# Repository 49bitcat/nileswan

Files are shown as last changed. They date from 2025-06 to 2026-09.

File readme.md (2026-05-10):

# nileswan

Open software, WS/WSC/PCv2 compatible flash cartridge.

## Building instructions

### Requirements

- [OSS CAD Suite](https://github.com/YosysHQ/oss-cad-suite-build) (FPGA core)
  - Requires a modified version of `icepack`, see below for more information
- [Wonderful Toolchain](https://wonderful.asie.pl/wiki/doku.php?id=getting_started)
  - `target-wswan` (IPL1, recovery, updater)
  - `toolchain-gcc-arm-none-eabi` (MCU firmware)
  - `wf-superfamiconv` (IPL1)
  - `wf-zx0-salvador` (IPL1, updater)
- CMake (MCU firmware)
- NASM (IPL0)
- Nim 2.0+ (FPGA core, IPL0)
- Ninja (MCU firmware)
- Python 3.x (SPI images, updater)
  - Including external libraries: `crc`
- dd, dosfstools, mtools (emulator images)

#### icepack

For the FPGA to be ready in time, the bitstream needs to be as small as possible and loaded at the highest speed possible. Thus a [modified branch of icepack](https://github.com/49bitcat/icestorm/tree/nileswan) has to be used.

### Compiling

1. Make sure to fetch the Git submodules: `git submodule update --init --recursive`.
2. Run `make help` to read what build options are possible.
3. Run `make` (or `make ...`) to build the requested components.

## License

- `docs/`: [CC BY-SA 4.0](https://creativecommons.org/licenses/by-sa/4.0/) (user and developer documentation)
- `firmware/`: GNU GPLv3+ (MCU firmware)
- `shell/`: [CC BY-SA 4.0](https://creativecommons.org/licenses/by-sa/4.0/) (cartridge shell STL files)
- `software/`: GNU GPLv3+ (cartridge IPL and on-device tools)
  * `software/libnile/`: zlib AND FatFs license

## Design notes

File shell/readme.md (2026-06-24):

# Shell

**If you previously printed the shell yourself or ordered it somewhere, please note that there was a mistake in the model which sometimes can lead to damage on the PCB. **

This can be easily be fixed by trimming the lid part near the button so that it looks as pictured:

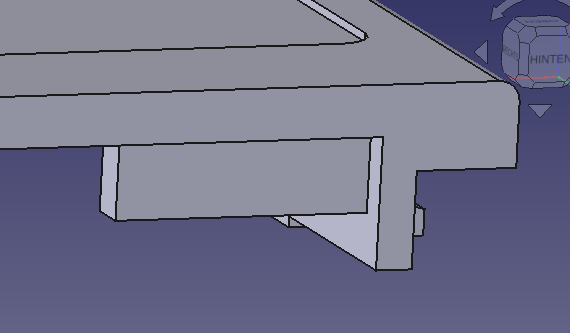
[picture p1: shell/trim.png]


The models have been updated that with the current files the issue does not exist anymore.

The nileswan shell consists of three parts: the bottom part where the PCB is inserted into, the lid which slides on similarly to as is seen on Game Boy cartridges and a cover for the cartridge button. A M2xL2xOD3.2 threaded insert in the lid and an M2x3 flat head screw hold the casing together.

Note that the files here are designed only with FDM printing in mind. They may have bad fitting or may not come out at all with other manufacturing processes.

For FDM printing the lid utilises a custom support piece, which is to be meant to be printed with an incompatible filament so that it can be later be pulled off leaving a clean surface for the label sticker to apply (our shells are printed in PETG with PLA used as support).

The button piece is best printed from PLA, PETG is too "droopy" for the fine details.

The files in this folder are licensed under the terms of [CC BY-SA 4.0](https://creativecommons.org/licenses/by-sa/4.0/).

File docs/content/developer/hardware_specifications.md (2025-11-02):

---
title: 'Hardware overview'
weight: 0
---

nileswan emulates the following hardware:

- Up to 16 MiB of ROM space
- Up to 512 KiB of RAM space, with battery back-up
- 2001 and 2003-compatible I/O ports, including port 0xCE
- Up to 2 KiB of EEPROM space (M93LC46, M93LC76 and M93LC86 compatible), with back-up
- S-3511A compatible real-time clock

In addition, nileswan provides the following native hardware facilities for user homebrew:

- Removable storage card, via SPI interface
- USB port for CDC serial transfers, via MCU and SPI interface
- 512 bytes of inter-process communication memory

## Flowchart

{{< mermaid class="text-center" >}}
flowchart LR
    CB[Cartridge bus]
    BAT[Backup battery]
    FPGA[ICE40HX1K FPGA]
    MCU[STM32U0 MCU]
    PSRAM[16 MiB PSRAM]
    SRAM[512 KiB SRAM]
    FLASH[SPI flash]
    USB[USB port]
    TF[TF card slot]
    ACCEL[Accelerometer]
    BUTTON[External button]

    BAT --> MCU
    BAT --> SRAM
    CB <--> FPGA
    FPGA <-->|SPI| MCU
    FPGA <--> PSRAM
    CB <--> PSRAM
    FPGA <--> SRAM
    CB <--> SRAM
    MCU <--> USB
    FPGA <-->|SPI| TF
    FPGA <-->|SPI| FLASH
    MCU <-->|I²C| ACCEL
    FPGA --- BUTTON
{{< /mermaid >}}

## Board revisions

| External | Internal | BOARD_REVISION |
| --- | --- | --- |
| pre-production | rev. 6 | `0x00` |
| pre-production | rev. 7 | `0x01` |
| pre-production | rev. 8 | `0x02` |
| REV-00 | rev. 9 | `0x02` |

## Limitations

Most of these limitations should not impact end users; however, documenting them may be of use to homebrew developers.

- RTC command timings are slightly slower than on real hardware. This is a compromise between accuracy and power consumption.
- EEPROM write and erase timings are not guaranteed to match real hardware. This may be improved in the future with firmware updates. Note that, in general, EEPROM write and erase timings are not guaranteed to be consistent across cartridges.
- Due to hardware limitations, the emulation of the MBM29DL400TC NOR flash chip used on certain cartridges is very limited. Writes are correctly passed through, but other commands, including erases, may be stubbed or unimplemented.
- The ability to set jumpers using GPIO pins is not yet implemented. This will be resolved in the future with a firmware update.
- No infrared transmitter or transceiver is present on the cartridge board.
- No sonar is connected to the cartridge board.
- If the 8-bit ROM access width is used, the native SPI area is not correctly mapped. This may be resolved in the future with a firmware update.

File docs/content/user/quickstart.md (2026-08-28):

---
title: 'Quick start guide'
weight: 0
---

To set up nileswan, you're going to need a removable storage card, sometimes referred to as a TF card, formatted
using the FAT16 or FAT32 file system.

{{< hint type=note >}}
Cards over 32 gigabytes may be formatted using the exFAT file system by default, which is not supported. In addition, only MBR partition tables are currently supported.

To ensure correct storage card formatting, you may wish to follow [the formatting guide](../troubleshooting/storage-card-formatting).
{{< /hint >}}

You're also going to need a *menu program*. This is the first program launched by nileswan's boot loader, stored in `/NILESWAN/MENU.WS`. The following options are currently available:

* **[swanshell](https://docs.asie.pl/swanshell/user/installation)** - the official main menu program.

{{< hint type=caution >}}
The boot loader doesn't support loading arbitrary programs. Do not use this functionality as an autoboot method; you will be disappointed.
{{< /hint >}}

With a menu program installed, you should be able to turn on your console with the nileswan cartridge inserted. Enjoy!

{{< hint type=note >}}
Unfortunately it is not always possible to ship a nileswan with a battery preinstalled. Please see this [guide](https://www.49bitcat.com/products/nileswan/battery_swap/) on suitable coin cell batteries and how to install them.

There should be a note accompanying your nileswan if the battery could not have been included, though swanshell will also warn you if it does not detect a battery.
{{< /hint >}}

If you run into problems, make sure to check the [Troubleshooting](../troubleshooting) section.

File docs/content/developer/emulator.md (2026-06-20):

---
title: 'Device emulator'
weight: 5
---

In addition to physical hardware, a device emulator can be used for testing nileswan software. There are two options available:

- [nileswan-medem](https://github.com/49bitcat/nileswan-medem/releases), a fork of the [Mednafen](https://mednafen.github.io/) emulator.
- [nileswan-mesem](https://github.com/49bitcat/nileswan-mesem/releases), a fork of the [MesenCE](https://github.com/nesdev-org/MesenCE/) emulator. More capable and accurate, but currently experimental.

These forks are maintained by us, so please do not ask the original/upstream developers questions about it.

The main advantage of the device emulator is that it allows much more rapid test cycles on a development computer. In addition,
stepping and breakpoint functionality is provided for debugging. The main disadvantage is that the emulator only implements
a limited subset of both the console and the cartridge's functionality.

## Installation

1. Download or compile the device emulator.
2. Prepare the emulator files. This can be done by either:
    - [downloading](https://github.com/49bitcat/nileswan/releases) a ready-made build of the package,
    - [compiling](https://github.com/49bitcat/nileswan) the package from source by using the `make dist-emu` command; in this case, the package will be placed in the `out/emulator` directory.
3. Place the emulator files in a directory of your choosing. You should have the following files:
    - `nileswan.ipl0` - a build of the IPL0 (first-stage loader),
    - `nileswan.spi` - a replica of the SPI flash image,
    - `nileswan.img` - a pre-formatted FAT32 image, emulating the removable storage card.
4. Use a tool of choice (for example, `mount -o loop nileswan.img ...` on Linux) to mount the pre-formatted FAT32 image and edit its contents.
5. Run the emulator: `nileswan-... nileswan.ipl0`.

## Supported features

| Feature | nileswan-medem | nileswan-mesem | Notes |
|---|---|---|---|
| SPI interface | Yes | Yes | |
| Power control | Yes | Yes | |
| SPI removable storage | Partial | Partial | Some commands only, <= 2 GiB only |
| SPI flash | Partial | Partial | Some commands only |
| MCU bootloader | Stubbed | Stubbed | MCU flash not stored |
| MCU native | Partial | Partial | Some commands only |
| MCU EEPROM | No | No | |
| MCU RTC | Partial | Partial | |
| MCU CDC transfer | Yes | No | On medem, use `wswan.excomm` config option |
| MCU accelerometer| Stubbed | Stubbed | |
| IPC area | Yes | Yes | |
| Flash FSM | Yes | Yes | |

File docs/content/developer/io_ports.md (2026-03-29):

---
title: 'I/O port map'
weight: 10
---
| Address |Width| Name | Description |
|---|-----|---|---|
| `0xE0` |  2  | SPI_CNT | SPI control register |
| `0xE2` |  1  | POW_CNT | Power control |
| `0xE3` |  1  | EMU_CNT  | Behavior control (EEPROM, flash emulation, ...) |
| `0xE4` |  2  | BANK_MASK  | Mask for bank index |
| `0xE6` (read)  |  1  | BOARD_REVISION | Board revision |
| `0xE6` (write) |  1  | WARMBOOT_CNT | Trigger FPGA warmboot |
| `0xE8` |  1  | IRQ_ENABLE | Cartridge IRQ enable |
| `0xE9` |  1  | IRQ_STATUS | Cartridge IRQ status |

## SPI interface

**`0xE0` - `SPI_CNT` (16-bit, read/write)**
| Bit(s) | Description |
|---|---|
|0-8|SPI transfer length in bytes minus one|
|9-10|Mode (0 = write, 1 = read, 2 = exchange, 3 = wait and read) |
|11|Transfer speed (0 = 24 MHz "high frequency clock", 1 = cartridge bus clock, usually 384 KHz) |
|12-13|Channel select/chip select (0 = no device selected and output to TF channel, 1 = select TF, 2 = select flash, 3 = select μC)|
|14|Memory mapped RX and TX buffer index (0-1)|
|15|Start/busy, when written (0 = abort transfer, 1 = start transfer), when read (0 = idle, 1 = transferring)|

* In read mode all output serial bits are 1. The incoming bits are stored in the RX buffer.
* In write mode bits from the TX buffer are output. The incoming serial bits are discarded.
* In exchange mode the TX buffer is output, while simultaneously the RX buffer is populated with incoming data.
* Wait and read mode behaves like read mode except bytes are only stored with the first byte received which is not 0xFF.

During transfer the data in the TX buffer currently not mapped into the address space is sent out. The received data is stored in the RX buffer currently not memory mapped. The transfer always starts from the beginning of the buffers.

All values besides the transfer abort are read only while a transfer is in progress.

Transfer aborting is not immediate for internal reasons and to allow the transfer to end cleanly on a byte boundary. After an abort is issued the busy bit will continue to be high until the abort is finally completed.

For EEPROM or RTC SPI communication to work, the cartridge serial clock has to be selected.

## Cartridge control

**`0xE2` - `POW_CNT` (8-bit, read/write)**

| Bit(s) | Description |
|---|---|
|0|Enable 24 MHz high frequency clock. (0=off, 1=on (default))|
|1|Enable TF power (0=off (default), 1=on)|
|2|Enable nileswan I/O registers (0=off, 1=on (default))|
|3|Enable 2001 mapper-specific I/O registers (0=off, 1=on (default))|
|4|Enable 2003 mapper-specific I/O registers (0=off, 1=on (default))|
|5|Pull μC BOOT0/μC busy high (0=no/μC may communicate via it, 1=yes)|
|6|Enable SRAM (0=off, 1=on (default))|
|7|μC reset line|

If `0xDD` is written to `POW_CNT` it will reset the entire register even if nileswan registers are disabled. This allows unlocking the nileswan I/O ports after they have been disabled.

Disabling a range of I/O registers only changes their visibility; it does not disable their functiion. E.g. the upper banking bits of the 2003 mapper continue to apply even if the registers used to change them are not accessible anymore.

The μC reset line bit is connected directly to the nRST pin of the microcontroller.

μC BOOT0 controls whether the microcontroller starts from bootloader ROM or programmable flash (see STM32 documentation). The line is shared with busy line for emulated EEPROM operations and is open drain idling at low.

If SRAM is enabled SRAM (banks 0-7) may be selected when accessing the RAM area.

**`0xE3` - `EMU_CNT` (8-bit, read/write)**

| Bit(s) | Description |
|---|---|
|0-1|Emulated EEPROM size (0=128B, 1=1KB, 2=2KB, 3=no EEPROM connected (default))|
|2|Flash emulation enable (0=disabled (default), 1=enabled)|
|3|Emulated ROM bus width (0=16-bit (default), 1=8-bit)|
|4|32 KB SRAM mirroring (0=disabled, 1=enabled)|
|5-7|Unused/0|

See section on EEPROM for details on EEPROM size.

When flash emulation the FPGA will provide minimal emulation of the programming sequences of parallel NOR flash memory for PSRAM accesses.

When 32 KB SRAM mirroring is enabled address line 15 of the SRAM is kept low, hence accesses to the upper 32 KB of each SRAM page are access the first 32 KB. Together with `BANK_MASK` it can be configured as if the cartridge contains a 32 KB SRAM.

**`0xE6` - `BOARD_REVISION` (8-bit, read)**

| Bit(s) | Description |
|---|---|
|0-7|Board revision|

Used for distinguishing boards during firmware updates.

|Value | Description |
|---|---|
| 0x00 | rev. 6 |
| 0x01 | rev. 7 |
| 0x02 | rev. 8 or 9 |
| 0x03 | rev. 9a |

**`0xE6` - `WARMBOOT_CNT` (8-bit, write)**

| Bit(s) | Description |
|---|---|
|0-1|Warmboot image to boot (0-3)|

After writing the FPGA will load one of four FPGA cores from SPI flash depending on the value written. The core image locations are documented in the SPI flash layout.

It may only be written while not running code from the cartridge. After writing, a wait of approximately 20 milliseconds is necessary until the cartridge responds again.

{{< hint type=important >}}
If your FPGA core image does not [enable](https://github.com/YosysHQ/icestorm/pull/332) a faster frequency range,
the wait may need to be as high as 53 milliseconds.
{{< /hint >}}

## Interrupt handling

**`0xE8` - `IRQ_ENABLE` (8-bit, read/write)**

| Bit(s) | Description |
|---|---|
|0|Pass MCU IRQ line|
|1|Pass button held|
|2-7|Unused/0|

**`0xE9` - `IRQ_STATUS` (8-bit, read/write)**

| Bit(s) | Description |
|---|---|
|0|MCU IRQ line|
|1|Button held|
|2-7|Unused/0|

## Banking

**`0xE4` - `BANK_MASK` (16-bit, read/write)**
| Bit(s) | Description |
|---|---|
|0-8|Mask to be applied to ROM bank index|
|9|Use mask for accesses in ROM0 area (0 = no, 1 = yes (default))|
|10|Use mask for accesses in ROM1 area (0 = no, 1 = yes (default))|
|11|Use mask for accesses in RAM area (0 = no, 1 = yes (default))|
|12-15|Mask to be applied to RAM bank index|

To allow booting from bootrom the masks are initialised with all bits set.

Bank mask is always applied to the extended ROM bank (starting from 0x40000).

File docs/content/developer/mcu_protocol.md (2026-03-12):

---
title: 'MCU firmware protocol'
weight: 50
---

This page documents protocols used to communicate with the on-board STM32 MCU via SPI.

## Bootloader protocol

This is the default mode after resetting with BOOT0 pulled high.

For details on this protocol, please refer to the ST Application note AN4286.

## Native mode

This is the default mode after resetting with BOOT0 pulled low.

To initiate a transaction, send a 16-bit little endian value (two bytes) declaring the command ID (in bits 0-6) and parameter (bits 7-15, values 0-511).

Every packet except "Switch to mode" has a response. The response always consists of the response header (two bytes) and the data.

The response header's bits 1-15 are the length of the following data, in bytes; bit 0 is set to 1 if an error has occured (for example, if the command is unknown).

### 0x00 - Echo

Test command. The parameter is the number of bytes to echo, followed by the bytes to echo.

### 0x01 - MCU: Switch to mode

The parameter is the ID of the mode of communication to use going forward:

- `0x00` - command mode
- `0x01` - EEPROM emulation mode
- `0x02` - RTC S-3511A emulation mode
- `0x03` - CDC output mode (transferred SPI bytes are output via USB CDC)
- `0xFF` - standby mode (requires reset to respond to SPI again)

### 0x02 - SPI: Set maximum frequency

The parameter is the maximum SPI transfer frequency that the MCU should be configured for (clock/pin speeds):

- `0x00` - 384 KHz
- `0x01` - 6 MHz
- `0x02` - 24 MHz

The response is 1 on success, 0 on failure.

So far, speeds faster than 384 KHz have been tested with the exception of commands with large (> 2-4 bytes) input parameter buffers.

### 0x03 - MCU: Get unique ID

The response is the unique ID of the chip.

### 0x04 - MCU: Read status information (protocol 1.2+)

The response is the following structure:

- byte 0..1: status
  - bit 0: 0 = RTC using internal clock, 1 = RTC using external clock
  - bit 1: 0 = RTC not active, 1 = RTC active
  - bit 2: 1 = USB plugged in
  - bit 3: 1 = USB connected to host
- byte 2..3: capabilities
  - bit 0: EEPROM
  - bit 1: USB
  - bit 2: accelerometer
  - bit 3: RTC
  - bit 4: battery back up (battery inserted)
- byte 4..5: reserved

This structure may grow in size in the future.

### 0x08 / 0x09 - MCU: Read / Write register (protocol 1.2+)

The parameter is the register address:

- 0x000: IRQ enable
  - bit 0: TF card inserted (edge)
  - bit 1: TF card removed (edge)
  - bit 2: RTC alarm (level)
- 0x001: IRQ status
- 0x002: IRQ status (automatic acknowledgement on read)

Each register is 2 bytes in size, and is passed as the argument or response.

### 0x0F - MCU: Get protocol version

The response is the *major*, followed by the *minor* version of the MCU protocol, as 16-bit little endian unsigned integers each.

| Firmware version | MCU protocol version |
|---|---|
| 1.0.0+ | 1.0 |
| 1.0.1+ | 1.1 |
| 1.1.0+ | 1.2 |

### 0x10 - EEPROM: Set emulation mode

Set the size of the emulated EEPROM:

- `0x00` - no EEPROM
- `0x01` - M93LC06
- `0x02` - M93LC46 compatible
- `0x03` - M93LC56 compatible
- `0x04` - M93LC66 compatible
- `0x05` - M93LC76 compatible
- `0x06` - M93LC86 compatible

The response is 1 on success, 0 on failure.

### 0x11 - EEPROM: Erase all data

The response is empty.

### 0x12 - EEPROM: Read data

The parameter is the number of words to read; the following word is the offset in words.

The response is the bytes read.

### 0x13 - EEPROM: Write data

The parameter is the number of words to write; the following word is the offset in words, then the words to write.

The response is empty.

### 0x14 - RTC: Send command

The parameter is the packet type to send to the emulated S-3511A, followed by the relevant bytes.

The response is the data returned by the emulated S-3511A.

### 0x15 - EEPROM: Get emulation mode

The response is 1 byte - the EEPROM emulation mode.

### 0x16 - MCU: Set save ID

The parameter specifies the save ID location:

- `0x01`: SRAM2 (if the save ID depends on data stored in SRAM2, such as EEPROM),
- `0x02`: RTC backup domain (if it doesn't),
- `0x03`: both.

The command is followed by four bytes of the save ID.

The save ID `0xFFFFFFFF` is reserved and means "no save is stored".

The response is 1 on success, 0 on failure.

### 0x17 - MCU: Get save ID

The parameter specifies the save ID location.

The response is four bytes of the save ID.

### 0x40 - USB: CDC: Read

The parameter is the maximum number of bytes to read. The value 0 is treated as 512 bytes.

The response is the data read from the CDC.

### 0x41 - USB: CDC: Write

The parameter is the number of bytes to write. The value 0 is treated as 512 bytes.

The response is two bytes in size and is the number of bytes successfully written.

### 0x42 - USB: HID: Write

The parameter is the length of the packet.

The data sent is two bytes - the result of a keypad scan.

The response is zero bytes in size.

### 0x43 - USB: CDC: Available

The response is the number of bytes that can be read from the CDC.

### 0x44 - USB: CDC: Clear

Clears the write and read buffers, removing any unread data.

No parameter, no response data.

### 0x50 - Accelerometer polling control

If the parameter is non-zero, the accelerometer is powered up and polled at the frequency equal to the parameter; for example, if the parameter is 100, the accelerometer will be polled at 100 Hz.

The frequency range is 1 .. 510 Hz. The parameter value 511 is reserved. 

If the parameter is zero, accelerometer polling is disabled.

A one byte response is given, 1 if the operation was successful and the accelerometer is present and 0 for the opposite.

### 0x51 - Accelerometer read

Returns three signed 16-bit words representing the measured acceleration on three axis X, Y and Z.

````

Plane representing Swan as held when playing horizontally.

Coordinate system is the local coordinate system of the accelerometer.
-Z is equivalent to the normal of the plane.

               ^ +Y
              /
     ________/________
+X  /       /        /
<----------0        /
  /        |       /
 /_________|______/
           |
           v +Z

````

The accelerometer is configured to work in a range of +/- 2 g with 10 bit fractional precision. This means that when the console is resting, the accelerometer will read a vector of magnitude 1024 the direction opposite to Earth's gravitational pull. E.g. if the console sits on the side with the EXT port a value of approximately (1024, 0, 0) will be read. See also: https://en.wikipedia.org/wiki/Accelerometer#Physical_principles and the datasheet of the used MXC400xXC series accelerometer.

### 0x7F - Reserved

Reserved to distinguish 0xFF bytes from commands.

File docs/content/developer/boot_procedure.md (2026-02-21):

---
title: 'Boot procedure'
weight: 30
---

nileswan uses a two-stage boot loader.

{{< mermaid class="text-center" >}}
flowchart LR
    C[Console IPL] -->|FPGA core 0| A0[IPL0]
    A0 -->|SPI flash| A1[IPL1 /boot/]
    A0 -->|SPI flash - button held| A5[IPL1 /factory/]
    A0 -->|SPI flash - X3 + B held| A3[IPL1 /safe/]
    A3 -->|SPI flash| A4[Recovery]
    A1 -->|FPGA core 1| A2[MENU.WS /on TF card/]
    A5 -->|FPGA core 0| A2[MENU.WS /on TF card/]
{{< /mermaid >}}

## IPL0

The first-stage boot loader is 512 bytes in size. It is stored in the factory FPGA core.

Its goal is to:

- reset the nileswan hardware,
- store the console register and I/O port state in console internal RAM,
- load IPL1 from SPI flash to console internal RAM.

## IPL1

The second-stage boot loader is up to `0x37C0` (14272) bytes in size. It is stored in the SPI flash. It uses a special 16-byte header:

|Offset|Size| Description |
|---|----|---|
| 0x0  | 2  | Load address (typically 0x0040) |
| 0x2  | 2  | Number of 512-byte sectors to load from SPI flash |
| 0x4  | 12 | Reserved |

It has two variants:

### IPL1 (boot)

The "boot" variant is bundled with the storage card driver. Its goal is to:

- validate the IPC memory area and populate it if necessary,
- switch to the update-provided FPGA core (unless the factory version of IPL1 is forced by holding the on-cartridge button),
- load `/NILESWAN/MENU.WS` from the storage card.

The "factory" variant is a version of the "boot" variant which does not load the updated firmware version's FPGA core, allowing
booting the system in the case of a corrupt firmware update.

To distinguish between the two variants, you can check the SPI control port's clock: in the "factory" variant, it is configured
to 384 KHz, while the standard "boot" variant sets it to 24 MHz.

### IPL1 (safe)

The "safe" variant instead reserves space for testing functionality, such as:

- performing a test of onboard PSRAM and SRAM memory,
- allowing to load a dedicated recovery program from SPI flash.

## Recovery

The recovery program is up to 256 KiB in size (or 192 KiB for the factory-provided version). It is formatted like a standard WS cartridge image.

It is better documented as part of the [User Guide](/user/troubleshooting/recovery).

## MENU.WS

The menu program is loaded to the final banks of PSRAM (bank `0xFF` downwards). It is formatted like a standard WS cartridge image.

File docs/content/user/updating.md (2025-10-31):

---
title: 'Updating firmware'
weight: 10
---

It is recommended to use the latest nileswan firmware. To update your firmware, proceed as follows:

1. Ensure your console's battery is fully charged. SPI and MCU flashing operations may cause brief periods of increased power draw.
2. Download the latest firmware update version from [here](https://github.com/49bitcat/nileswan/releases/latest/download/nileswan-fw-update.ws).
3. Launch the `.ws` file.

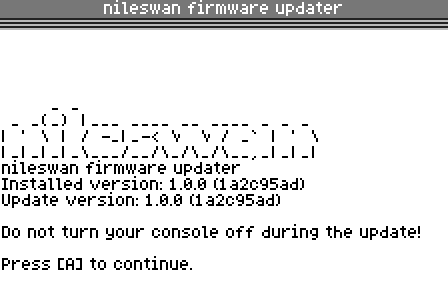
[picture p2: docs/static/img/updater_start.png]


4. After reviewing the messages, press `A` (or `Circle` on PCv2) to install.
5. Wait for the installation to complete. **Do not turn off the console** until the updater tells you it is safe to do so.

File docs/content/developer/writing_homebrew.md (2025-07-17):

---
title: 'Writing homebrew'
weight: 2
---

This article provides a brief overview of the basics of writing homebrew for nileswan. For more detailed information, make sure to study the other articles in the developer guide.

## Libraries

Users of the Wonderful toolchain can use [libnile](https://github.com/49bitcat/libnile), an official C library providing access to most of the cartridge's functionality. Documentation for libnile is available [here](https://49bitcat.com/docs/libnile/).

## Unlocking

After launching a program, nileswan cartridge functionality is locked by default. There are two separate unlocks required to take advantage of all its features, listed below.

### I/O unlock

By default, nileswan I/O ports are locked, that is not writable by software. One can unlock these I/O ports by writing the magic value `0xDD` to port `0xE2` (`POW_CNT`).

{{< hint type=note >}}
One can also write `0x00DD` to disable any cartridge behavior emulation features enabled by the menu program by default.
{{< /hint >}}

Note that this also performs all the operations of this value: disables TF card power, enables 24 MHz clock power, enables SRAM access, disables EEPROM emulation, flash emulation, et cetera. If you're using some of these features differently (such as not making use of the 24 MHz clock), it is recommended to follow this with a write that disables unused functionality.

In libnile, this corresponds to the `nile_io_unlock();` function.

### Bank unlock

However, this doesn't take care of banking.
By default, a mask is applied which prohibits accessing banks outside of the cartridge image's ROM and RAM space by mirroring that space.

In order to allow conveniently accessing nileswan-exclusive banks, functionality is provided to ignore this mask on a per-area basis (SRAM, ROM0, ROM1) via the `BANK_MASK` I/O port. In addition, for ROM banks, one has to use the extended 2003 banking ports (`0xD0`-`0xD5`), as their range on nileswan extends past 8 bits.

{{< hint type=caution >}}
ROM0 and ROM1 are typically allocated from bank `0xFF` down; however, cartridge images are loaded from `0x00` up. Disabling the bank mask on these areas can cause invalid data to be read unless the bank registers are adjusted to match.
{{< /hint >}}

In libnile, the `nile_bank_unlock();` function is provided, which automatically adjusts and unlocks SRAM, ROM0 and ROM1.

## MCU communication

### Initialization

If your homebrew requires nileswan-specific MCU functionality (such as USB access), remember that by default the MCU's native protocol will *not* be available. If the homebrew program requested EEPROM or RTC access, the MCU will be running in an emulation mode for the respective peripheral; otherwise, it would have been shut down to conserve power. As such, accessing the native MCU protocol requires an MCU reset; such a reset will also break non-nileswan-specific EEPROM/RTC communication code from working correctly.

In libnile, the `nile_mcu_reset(false);` function can be used to reset the MCU back to native mode.

### Faster transfer speeds

By default, the MCU is configured to communicate at a frequency of `384 KHz`. In some circumstances, faster communication speeds may be possible. This requires two distinct steps:

- configuring the MCU to accept faster SPI transfers (libnile: `nile_mcu_native_mcu_spi_set_speed_sync(...);`),
- configuring the FPGA and console to emit faster SPI clocks (libnile: `nile_spi_set_speed(...);`).

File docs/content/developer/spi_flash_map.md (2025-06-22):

---
title: 'SPI flash layout'
weight: 40
---

## Write-protected area

This area should be typically write-protected when running software.

|  Start | End | Description  |
|---|---|---|
| 0x000000 | 0x007FFF | FPGA bringup/factory core + header |
| 0x008000 | 0x00BFFF | IPL1 (factory) |
| 0x00C000 | 0x00EFFF | IPL1 (recovery) |
| 0x00F000 | 0x00FFFF | Firmware version (factory) |
| 0x010000 | 0x03FFFF | Recovery software (factory) |

## Non-write-protected area

|  Start | End | Description  |
|---|---|---|
| 0x040000 | 0x043FFF | IPL1 (updated) |
| 0x044000 | 0x04EFFF | Reserved |
| 0x04F000 | 0x04FFFF | Firmware version (updated) |
| 0x050000 | 0x07FFFF | Recovery software (updated) |
| 0x080000 | 0x087FFF | FPGA core 0 |
| 0x088000 | 0x08FFFF | FPGA core 1 |
| 0x090000 | 0x097FFF | FPGA core 2 |
| 0x098000 | 0x09FFFF | FPGA core 3 |
| 0x0A0000 | 0x1FFFFF | Unused (future expansion) |

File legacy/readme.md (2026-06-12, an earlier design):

These are legacy PCB/shell files from an old version of the cartridge's design.

They are kept for historical purposes only and not compatible with the current version of the software.

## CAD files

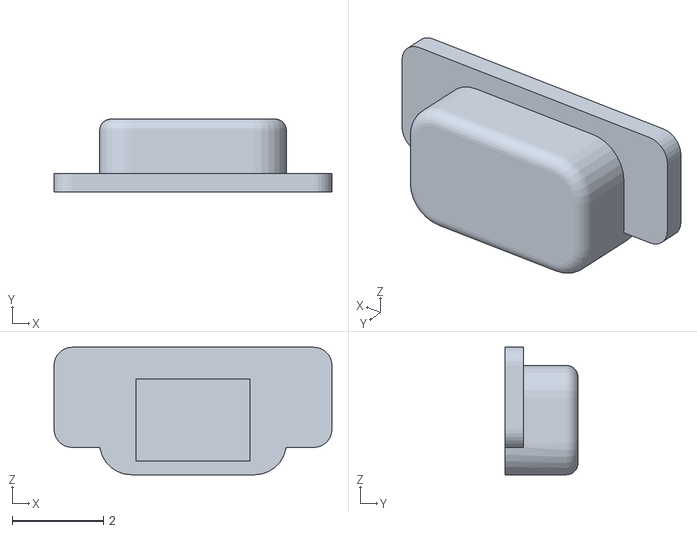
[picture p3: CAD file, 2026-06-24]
shell/nileswanButton.stl
6.10 x 1.60 x 2.80

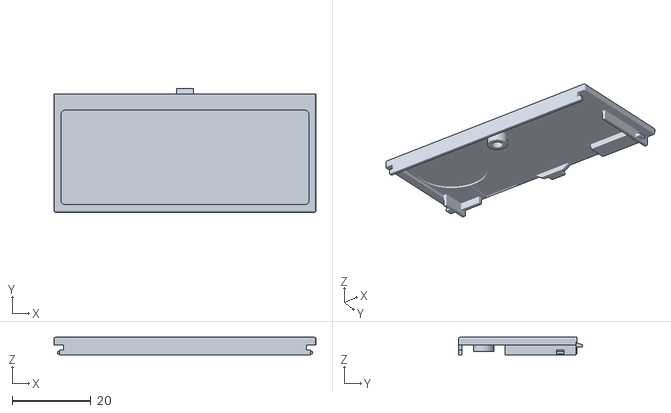
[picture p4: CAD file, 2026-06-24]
shell/nileswanLid.stl
66.6 x 31.5 x 4.50

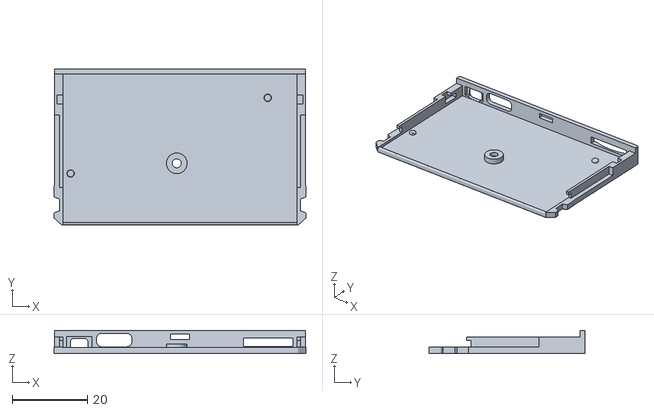
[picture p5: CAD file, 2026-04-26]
shell/nileswanBottomPart.stl
66.8 x 41.5 x 6.20

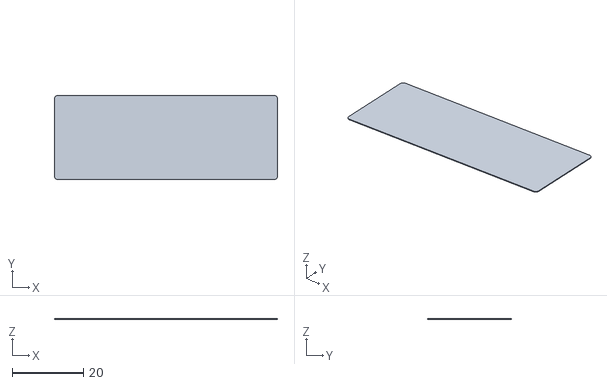
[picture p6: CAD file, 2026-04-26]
shell/nileswanLidPLASupport.stl
62.7 x 23.7 x 0.2

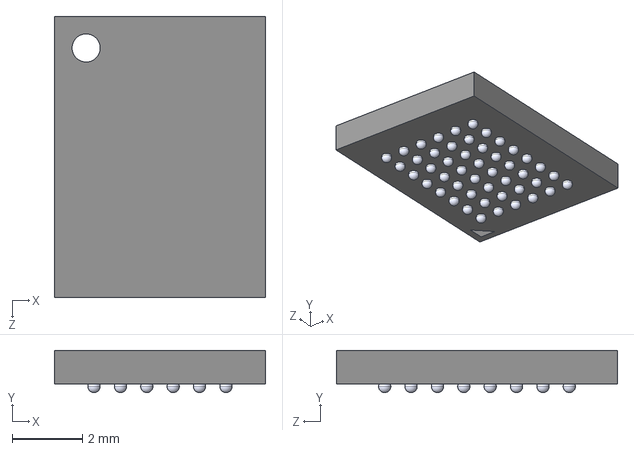
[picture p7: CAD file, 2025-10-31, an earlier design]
legacy/pcb/snapeda/models/IS66WVE4M16EBLL-70BLI.STEP
6.00 x 1.20 x 8.00 mm

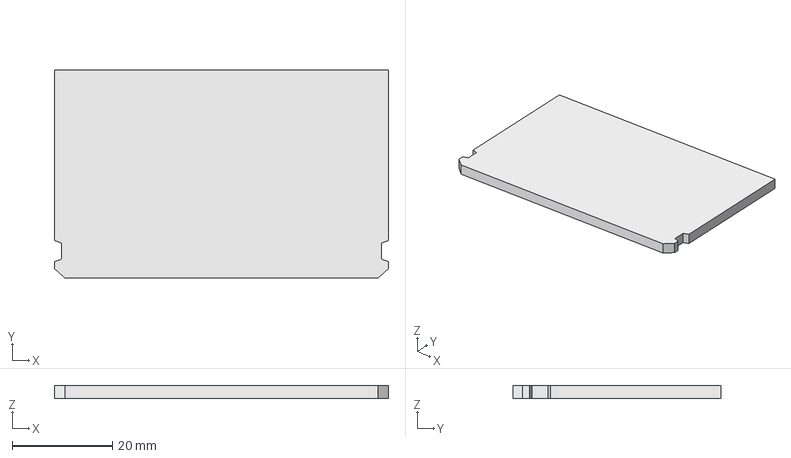
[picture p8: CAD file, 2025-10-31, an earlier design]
legacy/shell/shell.FCStd
66.5 x 41.5 x 2.60 mm

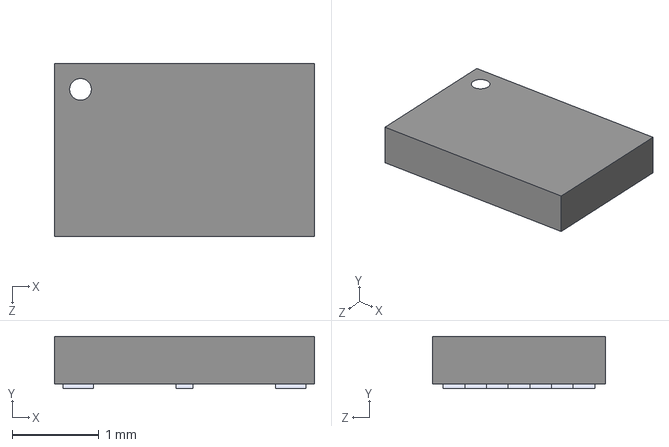
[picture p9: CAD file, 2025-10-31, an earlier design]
legacy/pcb/snapeda/models/W25Q16JVUXIQ.step
3.00 x 0.6 x 2.00 mm

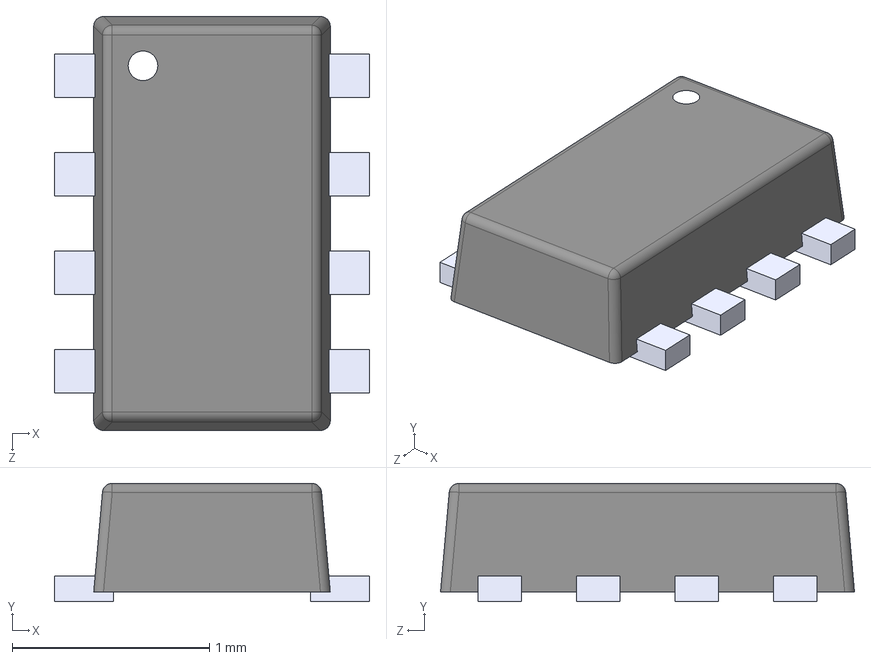
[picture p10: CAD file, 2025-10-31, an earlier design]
legacy/pcb/snapeda/models/TPS2117DRLR.step
1.60 x 0.6 x 2.10 mm

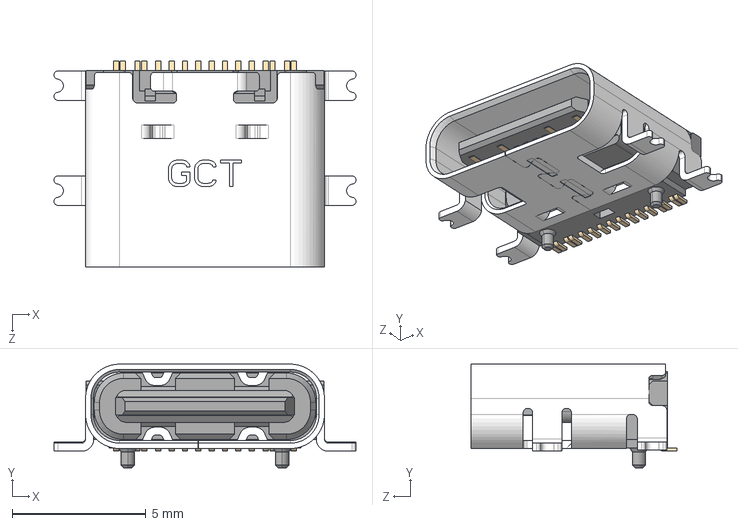
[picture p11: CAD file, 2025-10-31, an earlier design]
legacy/pcb/snapeda/models/USB4110GFA.step
11.3 x 3.89 x 7.70 mm

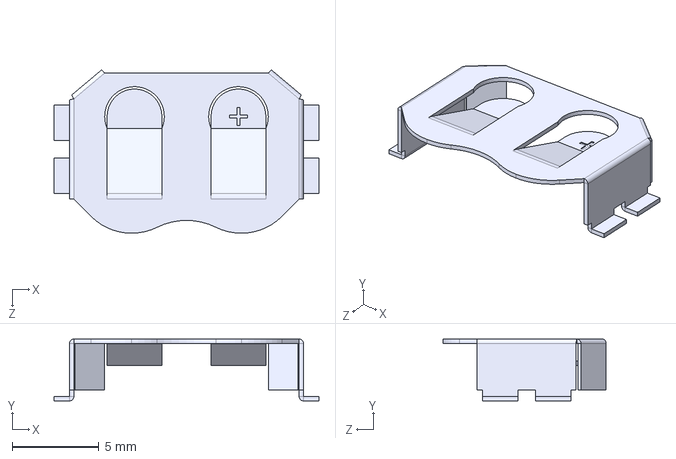
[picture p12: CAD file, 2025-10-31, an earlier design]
legacy/pcb/snapeda/models/BAT-HLD-012-SMT.step
15.2 x 3.56 x 9.40 mm

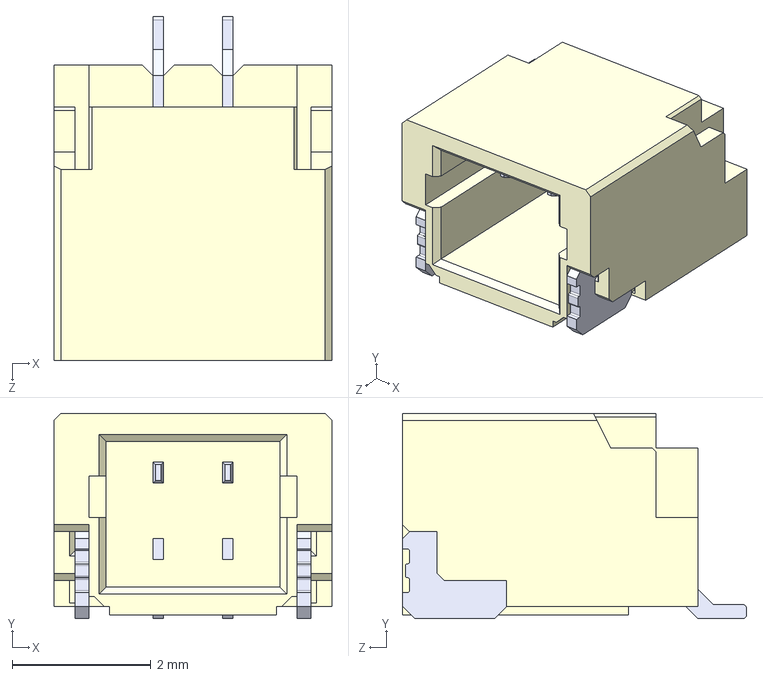
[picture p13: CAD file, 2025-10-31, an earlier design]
legacy/pcb/snapeda/models/SM02B-SRSS-TB_LF__SN_.step
4.00 x 2.95 x 4.95 mm

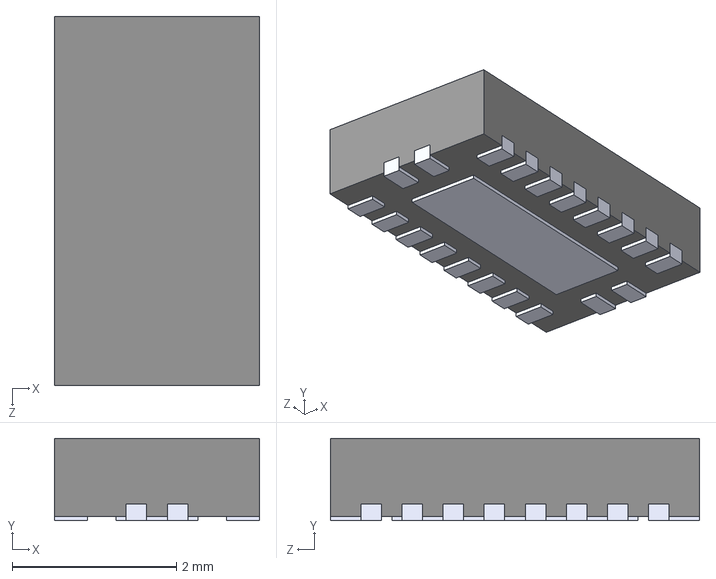
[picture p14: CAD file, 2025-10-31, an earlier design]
legacy/pcb/snapeda/models/74LVC245ABQ.step
2.50 x 1.00 x 4.50 mm

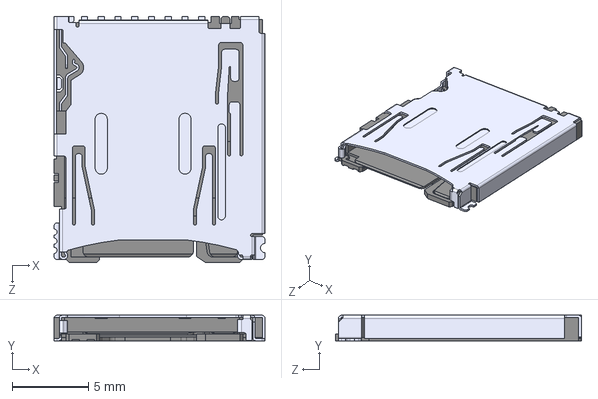
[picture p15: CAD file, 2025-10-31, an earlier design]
legacy/pcb/snapeda/models/DM3AT-SF-PEJM5--3DModel-STEP-418109.STEP
13.8 x 1.68 x 16.2 mm

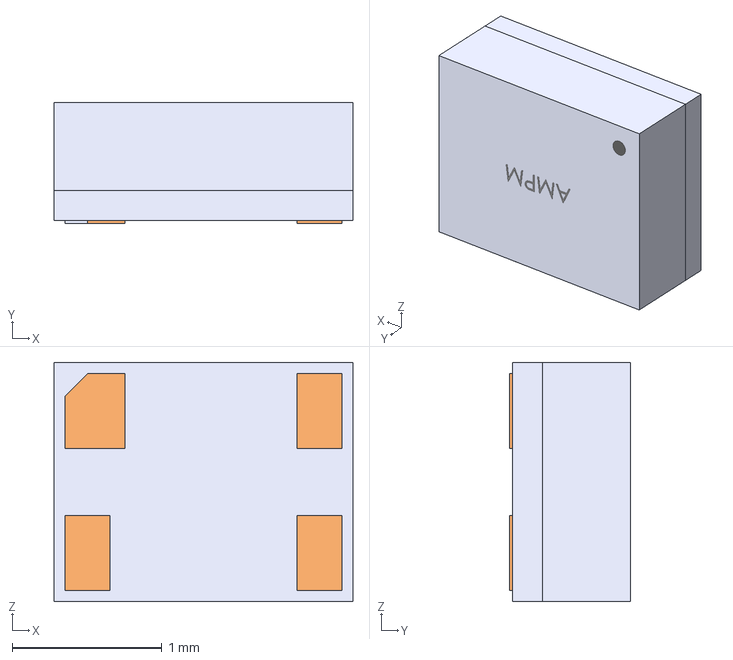
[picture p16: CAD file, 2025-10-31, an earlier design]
legacy/pcb/snapeda/models/AMPMAMPM_2.0 x 1.6 mm.step
2.00 x 0.811 x 1.60 mm

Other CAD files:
legacy/pcb/snapeda/models/SIT8021AI-J4-XXS-24.000000E.step
legacy/pcb/snapeda/models/W25Q16JVZPIQ.STEP
legacy/pcb/snapeda/models/TPS3619-50DGK.step

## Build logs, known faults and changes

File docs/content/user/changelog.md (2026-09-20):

---
title: 'Changelog'
weight: 100
---

## nileswan firmware DEV

- Bootloader
  - Added: Self-test routine for detecting some types of pin contact issues.
  - Changed: Improved compatibility with very early prototype consoles.
- Recovery
  - Fixed: The `Flash MCU firmware` option now flashes the correct firmware for the detected board revision.

## nileswan firmware 1.2.6 (26th August 2026)

- MCU firmware
  - Fixed: Improved battery power management.

## nileswan firmware 1.2.5 (21st June 2026)

- MCU firmware
  - Fixed: Issue regarding EEPROM memory management.
- Recovery
  - Added: SRAM/EEPROM data retention tests.
  - Added: Battery-backed MCU information lookup and tests.
  - Changed: Re-arranged menu hierarchy to be more user friendly.

## nileswan firmware 1.2.4 (16th June 2026)

- MCU firmware
  - General reliability improvements.

## nileswan firmware 1.2.3 (15th June 2026)

- FPGA core
  - General reliability improvements.
- MCU firmware
  - General reliability improvements.

## nileswan firmware 1.2.2 (7th June 2026)

- MCU firmware
  - General reliability improvements.
- Recovery IPL
  - Added: New quick memory test, focused on detecting address/data line faults.
  - Added: Visible warning for 24 MHz oscillator faults.
  - Fixed: Extended memory test failing all subsequent banks if one fails.
  - Fixed: ID readout in cases where the 24 MHz oscillator is non-functional.
- Updater
  - Added: Expanded SPI flash chip support.

## nileswan firmware 1.2.1 (13th May 2026*)

- Recovery
  - Changed: Tweaked manufacturing test.
- As this version does not change anything for end users, it will not be
  released as a flashable update.

## nileswan firmware 1.2.0 (10th May 2026)

- Factory FPGA core
  - Fixed: PCv2 consoles always starting in slow SPI mode.
  - Fixed: Improved startup reliability on aging "mono" WS consoles.
  - Note: These fixes requires a full reflash to be performed.
- MCU firmware
  - Fixed: Issues when querying the accelerometer while USB is plugged in.
  - Fixed: Issues when querying the onboard battery status.
- Recovery
  - Fixed: PCv2 input layout mapping.
- Updater
  - Fixed: PCv2 input layout mapping.

## nileswan firmware 1.1.1 (29th March 2026)

- MCU firmware
  - Fixed: Gamepad mode not functioning correctly on Windows machines.
  - Fixed: Issues when using the EEPROM mode while USB is plugged in.
  - Fixed: Worked around certain RTC mode reliability issues.
- Recovery
  - Added: MCU EEPROM test.

## nileswan firmware 1.1.0 (5th March 2026)

- FPGA core
  - Added: Emulation of the 0xCF I/O port mirror.
  - Added: Hardware support for faster SPI buffer access methods.
  - Fixed: Disabled I/O ports remaining readable.
  - Other minor improvements.
- Bootloader
  - Changed: Improved startup time.
- MCU firmware
  - Added: Support for detecting TF card insertion/removal.
  - Added: Support for reporting MCU status information back to console.
  - Fixed: Potential crash after disconnecting USB cable.
  - Fixed: Uncommon glitches during RTC communication.
- Recovery
  - Added: MCU status query tool.
  - Added: TF card insertion/removal test.
  - Fixed: Updated recovery program not using the updated FPGA core.

## nileswan firmware 1.0.3 (14th February 2026)

- MCU firmware
  - Updated: TinyUSB.
- Recovery
  - Added: onboard button test.
  - Added: PSRAM-SRAM stability test.
  - Added: TF card stability test.
  - Changed; Improved TF card benchmarks.
  - Fixed: Issues with TF card formatting.
- Other minor fixes and improvements.

## nileswan firmware 1.0.2 (18th November 2025)

- Bootloader:
  - Minor load time optimizations (~3-5% improvement).
- Recovery:
  - Fixed soft reset functionality.
  - Fixed storage card benchmarks not working without a forced re-initialization in some cases.
  - Fixed storage card formatting not working with some cards.
- Other minor fixes and improvements.

## nileswan firmware 1.0.1 (10th November 2025)

- MCU firmware:
  - Fixed response logic for undefined MCU commands.
  - Minor improvements to RTC and USB power management.
- Recovery:
  - Added support for printing cartridge information via USB.
  - Added support for printing the active MCU firmware's protocol version.
- Other minor fixes and improvements.

## nileswan firmware 1.0.0 (29th October 2025)

- Initial release.

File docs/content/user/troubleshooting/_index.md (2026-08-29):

---
title: 'Troubleshooting'
weight: 40
---

This page lists various nileswan issues that may be encountered, as well as solutions.

## Startup problems

### Console does not turn on with cartridge inserted

If no other cartridges work, this implies a fault with the console; fixing your console is outside the scope of this documentation.

If other cartridges work, the nileswan cartridge's contacts may be dirty. Clean up any dirt or grime on the contacts, then try re-inserting the cartridge.

Another option, particularly for original "mono" WS consoles, is that the capacitors have aged to a point where voltage ramps up too slowly for the nileswan cartridge to initialize.
If the console turns on unreliably, or the cartridge otherwise works fine on "color" units, this may be the reason. In this situation (and in general!), it is recommend to replace the console's capacitors.

{{< hint type=caution >}}
If you own a batch 1 nileswan, making a full *reflash* firmware update to version 1.2.0 or newer should help alleviate the problem.
{{< /hint >}}

Another option is that the factory FPGA core data may be corrupt. This is a brick scenario which cannot be recovered in software; as such, you will need to use an external SPI flashing device to resolve it.

Finally, there may be a hardware fault with the cartridge itself.

### Console displays a blank screen after finishing the splash screen sequence

This issue typically points to SPI flash data corruption.

The factory FPGA and IPL data may be intact. If so, follow the [Recovery -> Fixing corrupt update data](recovery#fixing-corrupt-update-data) guide, then install the latest firmware update.

If this alone does not help, the factory FPGA core data itself may be corrupt. In this case, software recovery cannot be guaranteed; as such, you will need to use an external SPI flashing device to resolve it.

## IPL problems

The initial program loader, or IPL, is responsible for loading an user-provided menu program from the removable storage card. In the case of an error, the screen turns black and an error message is displayed, like so:

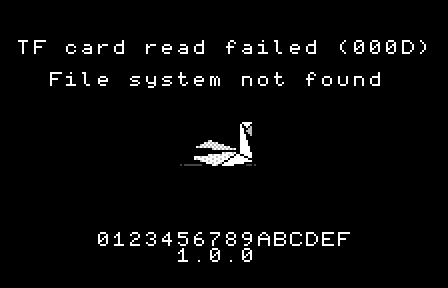
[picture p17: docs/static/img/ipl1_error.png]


Here are some common error messages. Note that an error may also point to a software bug, which may need to be reported to the developers.

**Pin contact error**

This can mean one of two issues:

- More commonly, this means a contact issue has been detected on one or more of the cartridge pins. Clean the cartridge contacts and try again.
- Less commonly, it can point towards a PSRAM chip fault. Launch the safe mode menu and use the *board check* or *memory test* option to diagnose the memory chips.

**Storage not ready**

The removable storage card was not detected. Please try re-inserting it.

**Storage I/O error**

The removable storage card was detected, but an error occured while reading from it. This could point to a hardware fault with the card itself.

**FAT filesystem not found**

The removable storage card was detected, but a FAT16/FAT32 file system was not detected.

nileswan does not currently support exFAT file systems or GPT partition tables. If your card is formatted using exFAT, you will need to manually format it to use FAT32. This is typically a problem for cards larger than 32 GiB.

**File not found**

The menu file (`/NILESWAN/MENU.WS`) was not found on the cartridge.

## Other problems

### Persistent data (save data, date/time, ...) corruption

This issue implies the SRAM and/or MCU are not receiving power.

Make sure a battery is inserted and that the battery holds charge. If that does not resolve the issue, it may point to a software bug or hardware fault.

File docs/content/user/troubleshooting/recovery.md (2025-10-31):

---
title: 'Recovery menu'
weight: 10
---

nileswan features a recovery menu.

1. Start the console while holding the **X3 + B** button combination (or **Esc + Up** on PCv2) to boot into safe mode. 

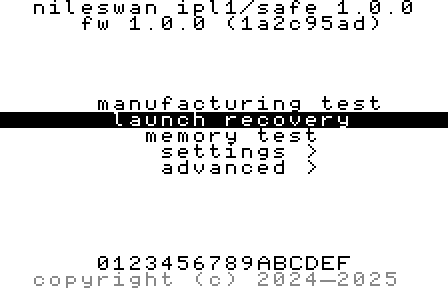
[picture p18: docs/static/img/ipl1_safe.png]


2. Use the up and down buttons to navigate to the **launch recovery** option, then press A (or **Circle** on PCv2).

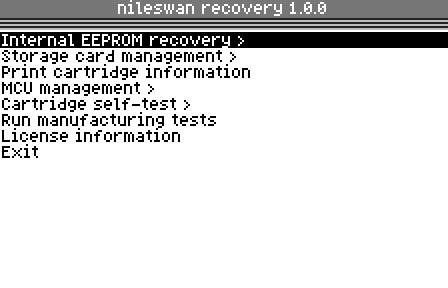
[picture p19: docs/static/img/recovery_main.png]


### Internal EEPROM recovery

Some console issues are caused by internal EEPROM corruption:

- a freeze on start can indicate corrupt splash screen data,
- LCD display issues can indicate corrupt LCD timing data on SC consoles with a TFT panel.

nileswan provides tools which may help in repairing a console with corrupt internal EEPROM data.

#### Disable custom splash

To disable custom splash on boot, one can use the following recovery feature:

1. Hold the button at the top of the cartridge.
2. While holding the button, turn on the console.

This forces the console's IPL to skip any splash screen data in the internal EEPROM.

A permanent solution is offered by the `Internal EEPROM recovery -> Disable custom splash` option in the cartridge recovery program.

#### Restore TFT panel data

To fix TFT panel display issues on SC consoles, one can use the `Internal EEPROM recovery -> Restore TFT panel data` option in the cartridge recovery program.

### Storage card management

This menu provides features related to managing the removable storage card, as well as evaluating its performance.

### Setup MCU boot flags

This is a manufacturing option used to configure the boot sequence of the microcontroller used on nileswan.

### Cartridge self-test

The cartridge comes with a set of self-test features used during manufacturing. These may allow you to diagnose certain hardware and firmware faults yourself. You can also run them in sequence with the `Run manufacturing tests` option.

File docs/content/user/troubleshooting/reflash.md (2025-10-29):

---
title: 'Firmware restore'
weight: 30
---

The IPL1 (second stage bootloader) or FPGA bitstream data may be corrupted as the result of a failed regular update.
This can manifest as a blank screen or as a crash on the initial splash screen (before the menu program is loaded).

nileswan provides a way to boot from the original firmware flashed at manufacturing. One can force the use of the factory IPL1 and FPGA bitstream by proceeding as follows:

1. Hold the physical button at the top of the cartridge.
2. While holding the physical button, turn on the console.
3. Keep holding the physical button until the console's splash screen appears.

From here, you should be able to use the menu software to perform [a standard firmware update](../../updating).

## Factory reflash

Alternatively, if one so chooses, one can also perform a full factory reflash. This updates both the regular and manufacturing copies of the
firmware.

{{< hint type=warning >}}
If the factory reflash fails, the cartridge may be bricked in a way which requires external SPI flashing.

You are performing this procedure at your own risk!
{{< /hint >}}

1. Ensure your console's battery is fully charged.
2. Download the latest firmware reflash image version from [here](https://github.com/49bitcat/nileswan/releases/latest/download/nileswan-fw-reflash.ws).
3. Launch the `.ws` file.
4. After reviewing the messages, press `A` (or `Circle` on PCv2) to install.
5. Wait for the installation to complete. **Do not turn off the console** until the updater tells you it is safe to do so.

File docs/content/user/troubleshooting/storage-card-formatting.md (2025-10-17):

---
title: 'Storage card formatting'
weight: 20
---

nileswan has been tested with external storage cards up to 32 GiB in size. Storage cards formatted with the FAT16 or FAT32 file system up to 2 TiB in size should be supported as well. **exFAT is not currently supported!**

## Via recovery menu

The most reliable way to format the external storage card is using the on-device recovery menu.

1. Start the console while holding the **X3 + B** button combination (or **Esc + Up** on PCv2). You will enter the cartridge's safe mode.
2. Use up/down buttons to navigate to the **launch recovery** option, then press A (or **Circle** on PCv2).
3. Navigate to **Storage card management**, then to **Format storage card**.
4. Follow the on-screen instructions.

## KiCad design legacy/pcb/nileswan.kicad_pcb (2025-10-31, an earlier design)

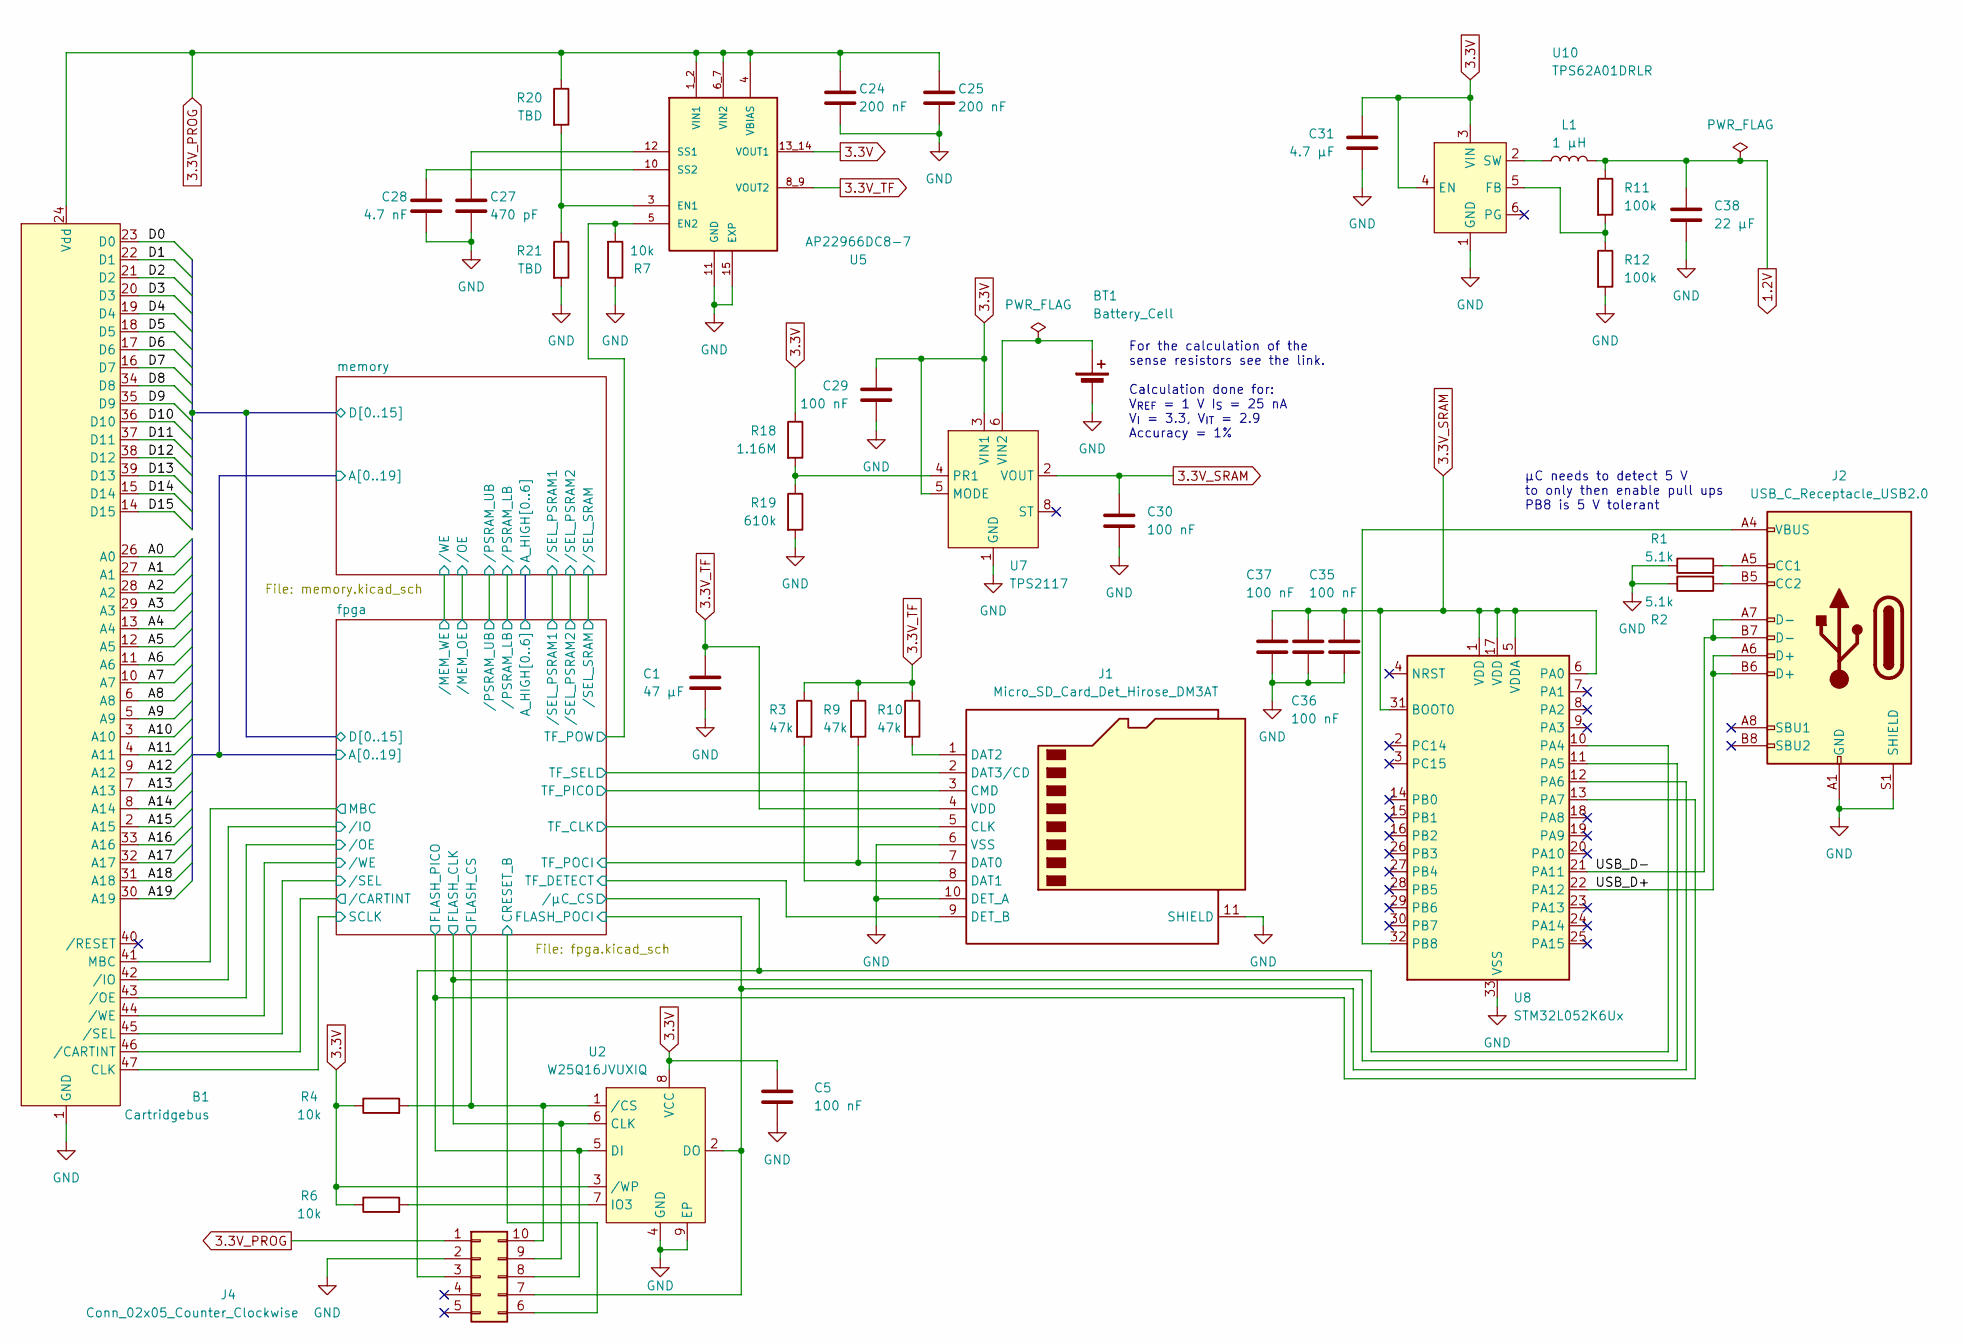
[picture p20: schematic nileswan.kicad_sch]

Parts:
B1: Cartridgebus; WSCartridgeBus
BT1: Battery_Cell; BAT_BAT-HLD-012-SMT
C1: 47 μF; C_0805_2012Metric
C5, C29, C30, C35, C36, C37: 100 nF; C_0402_1005Metric
C24, C25: 200 nF; C_0402_1005Metric
C27: 470 pF; C_0402_1005Metric
C28: 4.7 nF; C_0402_1005Metric
C31: 4.7 μF; C_0603_1608Metric
C38: 22 μF; C_0603_1608Metric
J1: Micro_SD_Card_Det_Hirose_DM3AT; microSD_HC_Hirose_DM3AT-SF-PEJM5
J2: USB_C_Receptacle_USB2.0; USB_C_Receptacle_GCT_USB4110
J4: Conn_02x05_Counter_Clockwise; Tag-Connect_TC2050-IDC-NL_2x05_P1.27mm_Vertical
L1: 1 μH; L_Murata_DFE201610P
R1, R2: 5.1k; R_0402_1005Metric
R3, R9, R10: 47k; R_0402_1005Metric
R4, R6, R7: 10k; R_0402_1005Metric
R11, R12: 100k; R_0402_1005Metric
R18: 1.16M; R_0402_1005Metric
R19: 610k; R_0402_1005Metric
R20, R21: TBD; R_0402_1005Metric
U2: W25Q16JVUXIQ; SON50P300X200X60-9N
U5: AP22966DC8-7; IC_AP22966DC8-7; PARTREV 3-2
U7: TPS2117; SOTFL50P160X60-8N
U8: STM32L052K6Ux; QFN-32-1EP_5x5mm_P0.5mm_EP3.45x3.45mm
U10: TPS62A01DRLR; SOT-563

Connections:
1.2V: C38.1, L1.2, R11.1; also elsewhere on the board
3.3V: C5.1, C29.1, C31.1, R4.1, R6.1, R18.1, U2.3 (/WP), U2.8 (VCC), U5.13_14 (VOUT1), U7.3 (VIN1), U7.5 (MODE), U10.3 (VIN), U10.4 (EN); also elsewhere on the board
3.3V_PROG: B1.24 (Vdd), B1.25 (Vdd), C24.1, C25.1, J4.1, R20.1, U5.1_2 (VIN1), U5.4 (VBIAS), U5.6_7 (VIN2)
3.3V_SRAM: C30.1, C35.1, C36.1, C37.1, U7.2 (VOUT), U7.7 (VOUT), U8.1 (VDD), U8.5 (VDDA), U8.6 (PA0), U8.17 (VDD), U8.31 (BOOT0); also elsewhere on the board
3.3V_TF: C1.1, J1.4 (VDD), R3.1, R9.1, R10.1, U5.8_9 (VOUT2)
/USB_D+: J2.A6 (D+), J2.B6 (D+), U8.22 (PA12)
/USB_D-: J2.A7 (D-), J2.B7 (D-), U8.21 (PA11)
/fpga/A0: B1.26 (A0); also elsewhere on the board
/fpga/A1: B1.27 (A1); also elsewhere on the board
/fpga/A2: B1.28 (A2); also elsewhere on the board
/fpga/A3: B1.29 (A3); also elsewhere on the board
/fpga/A4: B1.13 (A4); also elsewhere on the board
/fpga/A5: B1.12 (A5); also elsewhere on the board
/fpga/A6: B1.11 (A6); also elsewhere on the board
/fpga/A7: B1.10 (A7); also elsewhere on the board
/fpga/A8: B1.6 (A8); also elsewhere on the board
/fpga/A9: B1.5 (A9); also elsewhere on the board
/fpga/A10: B1.3 (A10); also elsewhere on the board
/fpga/A11: B1.4 (A11); also elsewhere on the board
/fpga/A12: B1.9 (A12); also elsewhere on the board
/fpga/A13: B1.7 (A13); also elsewhere on the board
/fpga/A14: B1.8 (A14); also elsewhere on the board
/fpga/A15: B1.2 (A15); also elsewhere on the board
/fpga/A16: B1.33 (A16); also elsewhere on the board
/fpga/A17: B1.32 (A17); also elsewhere on the board
/fpga/A18: B1.31 (A18); also elsewhere on the board
/fpga/A19: B1.30 (A19); also elsewhere on the board
/fpga/CRESET_B: J4.6; also elsewhere on the board
/fpga/D0: B1.23 (D0); also elsewhere on the board
/fpga/D1: B1.22 (D1); also elsewhere on the board
/fpga/D2: B1.21 (D2); also elsewhere on the board
/fpga/D3: B1.20 (D3); also elsewhere on the board
/fpga/D4: B1.19 (D4); also elsewhere on the board
/fpga/D5: B1.18 (D5); also elsewhere on the board
/fpga/D6: B1.17 (D6); also elsewhere on the board
/fpga/D7: B1.16 (D7); also elsewhere on the board
/fpga/D8: B1.34 (D8); also elsewhere on the board
/fpga/D9: B1.35 (D9); also elsewhere on the board
/fpga/D10: B1.36 (D10); also elsewhere on the board
/fpga/D11: B1.37 (D11); also elsewhere on the board
/fpga/D12: B1.38 (D12); also elsewhere on the board
/fpga/D13: B1.39 (D13); also elsewhere on the board
/fpga/D14: B1.15 (D14); also elsewhere on the board
/fpga/D15: B1.14 (D15); also elsewhere on the board
/fpga/FLASH_CLK: J4.9, U2.6 (CLK), U8.11 (PA5); also elsewhere on the board
/fpga/FLASH_CS: J4.10, R4.2, U2.1 (/CS); also elsewhere on the board
/fpga/FLASH_PICO: J4.8, U2.5 (DI), U8.13 (PA7); also elsewhere on the board
/fpga/FLASH_POCI: J4.7, U2.2 (DO), U8.12 (PA6); also elsewhere on the board
/fpga/MBC: B1.41 (MBC); also elsewhere on the board
/fpga/SCLK: B1.47 (CLK); also elsewhere on the board
/fpga/TF_CLK: J1.5 (CLK); also elsewhere on the board
/fpga/TF_DETECT: J1.9 (DET_B); also elsewhere on the board
/fpga/TF_PICO: J1.3 (CMD); also elsewhere on the board
/fpga/TF_POCI: J1.7 (DAT0), R9.2; also elsewhere on the board
/fpga/TF_POW: R7.2, U5.5 (EN2); also elsewhere on the board
/fpga/TF_SEL: J1.2 (DAT3/CD); also elsewhere on the board
/fpga//CARTINT: B1.46 (/CARTINT); also elsewhere on the board
/fpga//IO: B1.42 (/IO); also elsewhere on the board
/fpga//OE: B1.43 (/OE); also elsewhere on the board
/fpga//SEL: B1.45 (/SEL); also elsewhere on the board
/fpga//WE: B1.44 (/WE); also elsewhere on the board
/fpga//μC_CS: J4.3, U8.10 (PA4); also elsewhere on the board
GND: B1.1 (GND), B1.48 (GND), BT1.2 (-), C1.2, C5.2, C24.2, C25.2, C27.2, C28.2, C29.2, C30.2, C31.2, C35.2, C36.2, C37.2, C38.2, J1.6 (VSS), J1.10 (DET_A), J1.11 (SHIELD), J2.A1 (GND), J2.A12 (GND), J2.B1 (GND), J2.B12 (GND), J2.S1 (SHIELD), J4.2, R1.1, R2.1, R7.1, R12.2, R19.2, R21.2, U2.4 (GND), U2.9 (EP), U5.11 (GND), U5.15 (EXP), U7.1 (GND), U8.33 (VSS), U10.1 (GND); also elsewhere on the board
unnamed: BT1.1 (+), U7.6 (VIN2)
unnamed: J1.8 (DAT1), R3.2
unnamed: J1.1 (DAT2), R10.2
unnamed: J2.A5 (CC1), R1.2
unnamed: J2.B5 (CC2), R2.2
unnamed: R6.2, U2.7 (IO3)
unnamed: R20.2, R21.1, U5.3 (EN1)
unnamed: C27.1, U5.12 (SS1)
unnamed: C28.1, U5.10 (SS2)
unnamed: R18.2, R19.1, U7.4 (PR1)
unnamed: J2.A4 (VBUS), J2.A9 (VBUS), J2.B4 (VBUS), J2.B9 (VBUS), U8.32 (PB8)
unnamed: R11.2, R12.1, U10.5 (FB)
unnamed: L1.1, U10.2 (SW)

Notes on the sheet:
μC needs to detect 5 V to only then enable pull ups PB8 is 5 V tolerant
For the calculation of the sense resistors see the link. Calculation done for: V_{REF} = 1 V I_{S} = 25 nA V_{I} = 3.3, V_{IT} = 2.9 Accuracy = 1%

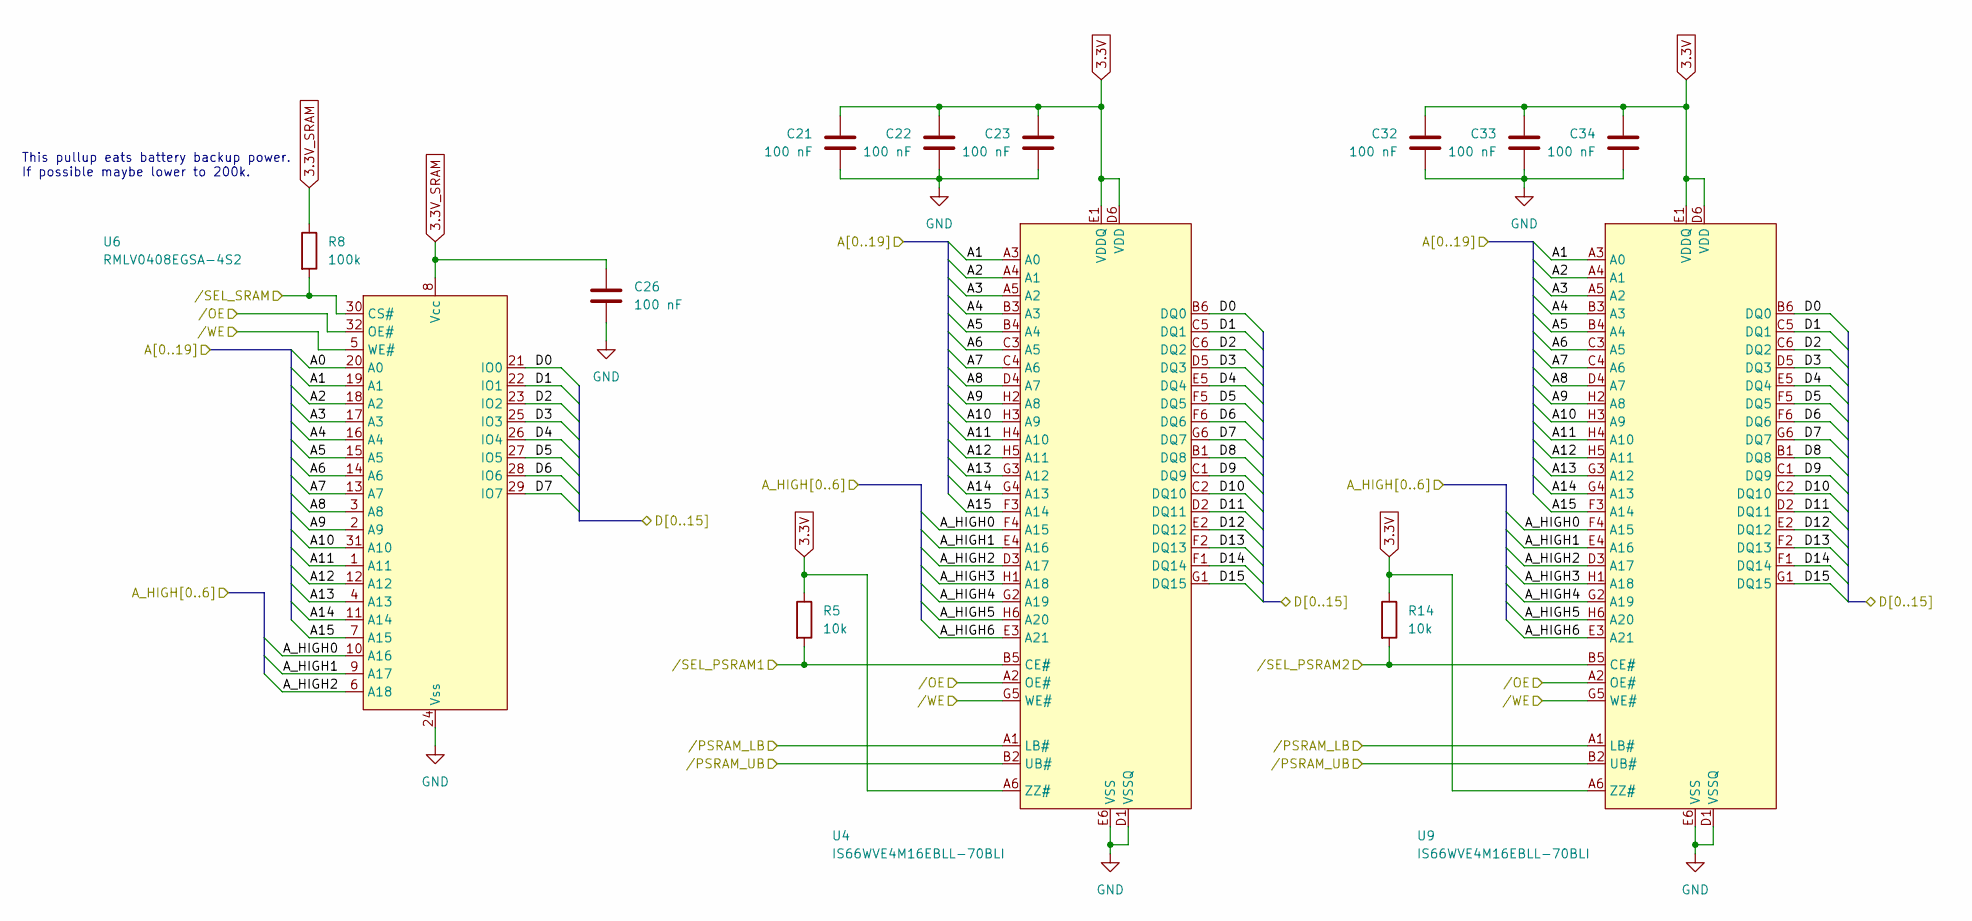
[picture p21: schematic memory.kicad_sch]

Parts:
C21, C22, C23, C26, C32, C33, C34: 100 nF; C_0402_1005Metric
R5, R14: 10k; R_0402_1005Metric
R8: 100k; R_0402_1005Metric
U4, U9: IS66WVE4M16EBLL-70BLI; BGA-48_6x8_6.0x8.0mm
U6: RMLV0408EGSA-4S2; sTSOP-32

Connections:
3.3V: C21.2, C22.2, C23.2, C32.2, C33.2, C34.2, R5.1, R14.1, U4.A6 (ZZ#), U4.D6 (VDD), U4.E1 (VDDQ), U9.A6 (ZZ#), U9.D6 (VDD), U9.E1 (VDDQ); also elsewhere on the board
3.3V_SRAM: C26.2, R8.1, U6.8 (Vcc); also elsewhere on the board
/fpga/A0: U6.20 (A0); also elsewhere on the board
/fpga/A1: U4.A3 (A0), U6.19 (A1), U9.A3 (A0); also elsewhere on the board
/fpga/A2: U4.A4 (A1), U6.18 (A2), U9.A4 (A1); also elsewhere on the board
/fpga/A3: U4.A5 (A2), U6.17 (A3), U9.A5 (A2); also elsewhere on the board
/fpga/A4: U4.B3 (A3), U6.16 (A4), U9.B3 (A3); also elsewhere on the board
/fpga/A5: U4.B4 (A4), U6.15 (A5), U9.B4 (A4); also elsewhere on the board
/fpga/A6: U4.C3 (A5), U6.14 (A6), U9.C3 (A5); also elsewhere on the board
/fpga/A7: U4.C4 (A6), U6.13 (A7), U9.C4 (A6); also elsewhere on the board
/fpga/A8: U4.D4 (A7), U6.3 (A8), U9.D4 (A7); also elsewhere on the board
/fpga/A9: U4.H2 (A8), U6.2 (A9), U9.H2 (A8); also elsewhere on the board
/fpga/A10: U4.H3 (A9), U6.31 (A10), U9.H3 (A9); also elsewhere on the board
/fpga/A11: U4.H4 (A10), U6.1 (A11), U9.H4 (A10); also elsewhere on the board
/fpga/A12: U4.H5 (A11), U6.12 (A12), U9.H5 (A11); also elsewhere on the board
/fpga/A13: U4.G3 (A12), U6.4 (A13), U9.G3 (A12); also elsewhere on the board
/fpga/A14: U4.G4 (A13), U6.11 (A14), U9.G4 (A13); also elsewhere on the board
/fpga/A15: U4.F3 (A14), U6.7 (A15), U9.F3 (A14); also elsewhere on the board
/fpga/A_HIGH0: U4.F4 (A15), U6.10 (A16), U9.F4 (A15); also elsewhere on the board
/fpga/A_HIGH1: U4.E4 (A16), U6.9 (A17), U9.E4 (A16); also elsewhere on the board
/fpga/A_HIGH2: U4.D3 (A17), U6.6 (A18), U9.D3 (A17); also elsewhere on the board
/fpga/A_HIGH3: U4.H1 (A18), U9.H1 (A18); also elsewhere on the board
/fpga/A_HIGH4: U4.G2 (A19), U9.G2 (A19); also elsewhere on the board
/fpga/A_HIGH5: U4.H6 (A20), U9.H6 (A20); also elsewhere on the board
/fpga/A_HIGH6: U4.E3 (A21), U9.E3 (A21); also elsewhere on the board
/fpga/D0: U4.B6 (DQ0), U6.21 (IO0), U9.B6 (DQ0); also elsewhere on the board
/fpga/D1: U4.C5 (DQ1), U6.22 (IO1), U9.C5 (DQ1); also elsewhere on the board
/fpga/D2: U4.C6 (DQ2), U6.23 (IO2), U9.C6 (DQ2); also elsewhere on the board
/fpga/D3: U4.D5 (DQ3), U6.25 (IO3), U9.D5 (DQ3); also elsewhere on the board
/fpga/D4: U4.E5 (DQ4), U6.26 (IO4), U9.E5 (DQ4); also elsewhere on the board
/fpga/D5: U4.F5 (DQ5), U6.27 (IO5), U9.F5 (DQ5); also elsewhere on the board
/fpga/D6: U4.F6 (DQ6), U6.28 (IO6), U9.F6 (DQ6); also elsewhere on the board
/fpga/D7: U4.G6 (DQ7), U6.29 (IO7), U9.G6 (DQ7); also elsewhere on the board
/fpga/D8: U4.B1 (DQ8), U9.B1 (DQ8); also elsewhere on the board
/fpga/D9: U4.C1 (DQ9), U9.C1 (DQ9); also elsewhere on the board
/fpga/D10: U4.C2 (DQ10), U9.C2 (DQ10); also elsewhere on the board
/fpga/D11: U4.D2 (DQ11), U9.D2 (DQ11); also elsewhere on the board
/fpga/D12: U4.E2 (DQ12), U9.E2 (DQ12); also elsewhere on the board
/fpga/D13: U4.F2 (DQ13), U9.F2 (DQ13); also elsewhere on the board
/fpga/D14: U4.F1 (DQ14), U9.F1 (DQ14); also elsewhere on the board
/fpga/D15: U4.G1 (DQ15), U9.G1 (DQ15); also elsewhere on the board
/fpga//MEM_OE: U4.A2 (OE#), U6.32 (OE#), U9.A2 (OE#); also elsewhere on the board
/fpga//MEM_WE: U4.G5 (WE#), U6.5 (WE#), U9.G5 (WE#); also elsewhere on the board
/fpga//PSRAM_LB: U4.A1 (LB#), U9.A1 (LB#); also elsewhere on the board
/fpga//PSRAM_UB: U4.B2 (UB#), U9.B2 (UB#); also elsewhere on the board
/fpga//SEL_PSRAM1: R5.2, U4.B5 (CE#); also elsewhere on the board
/fpga//SEL_PSRAM2: R14.2, U9.B5 (CE#); also elsewhere on the board
/fpga//SEL_SRAM: R8.2, U6.30 (CS#); also elsewhere on the board
GND: C21.1, C22.1, C23.1, C26.1, C32.1, C33.1, C34.1, U4.D1 (VSSQ), U4.E6 (VSS), U6.24 (Vss), U9.D1 (VSSQ), U9.E6 (VSS); also elsewhere on the board

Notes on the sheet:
This pullup eats battery backup power. If possible maybe lower to 200k.

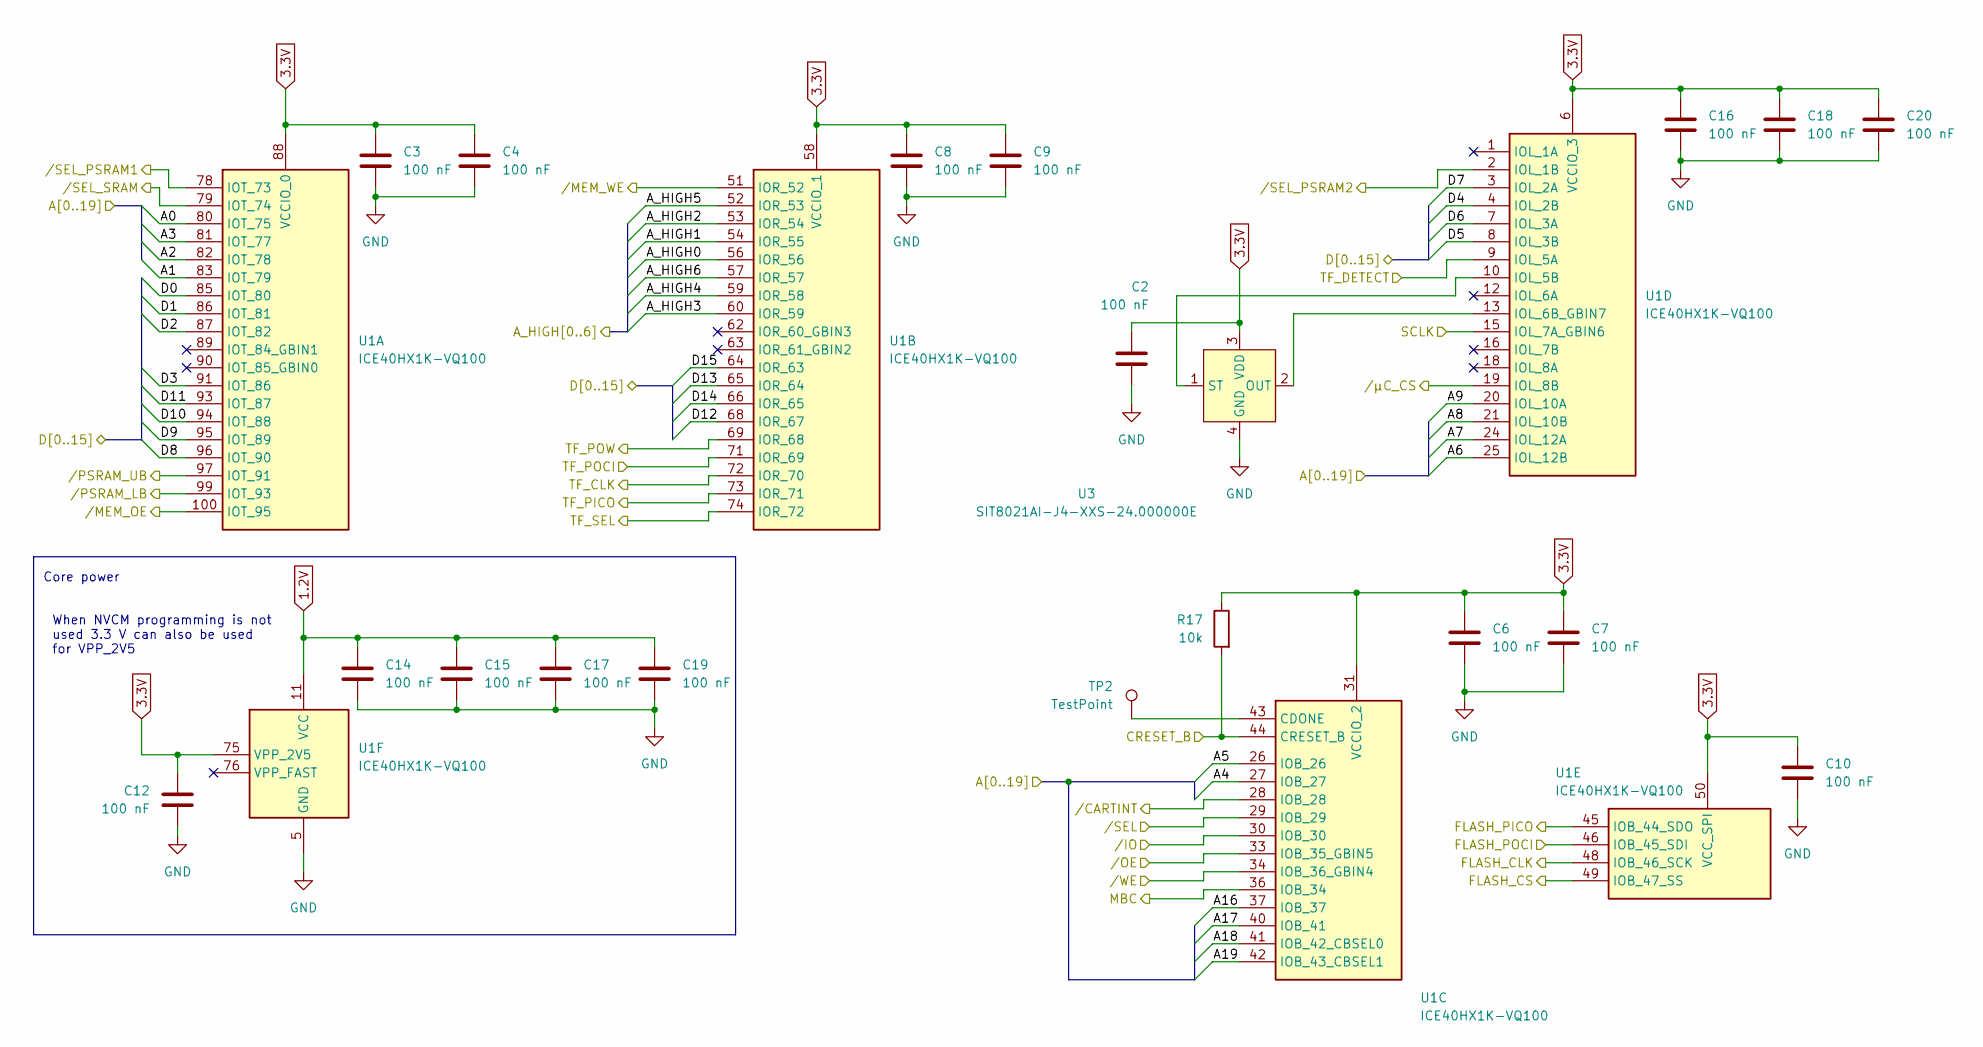
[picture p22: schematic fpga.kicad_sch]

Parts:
C2, C3, C4, C6, C7, C8, C9, C10, C12, C14, C15, C16, C17, C18, C19, C20: 100 nF; C_0402_1005Metric
R17: 10k; R_0402_1005Metric
TP2: TestPoint; TestPoint_Pad_D1.0mm
U1: ICE40HX1K-VQ100; VQFP-100_14x14mm_P0.5mm
U3: SIT8021AI-J4-XXS-24.000000E; BGA4N41X100P2X2_84X154X60N

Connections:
1.2V: C14.1, C15.1, C17.1, C19.1, U1.11 (VCC), U1.35 (VCC), U1.61 (VCC), U1.77 (VCC); also elsewhere on the board
3.3V: C2.1, C3.1, C4.1, C6.1, C7.1, C8.1, C9.1, C10.1, C12.1, C16.1, C18.1, C20.1, R17.1, U1.6 (VCCIO_3), U1.14 (VCCIO_3), U1.22 (VCCIO_3), U1.31 (VCCIO_2), U1.38 (VCCIO_2), U1.50 (VCC_SPI), U1.58 (VCCIO_1), U1.67 (VCCIO_1), U1.75 (VPP_2V5), U1.88 (VCCIO_0), U1.92 (VCCIO_0), U3.3 (VDD); also elsewhere on the board
/fpga/A0: U1.80 (IOT_75); also elsewhere on the board
/fpga/A1: U1.83 (IOT_79); also elsewhere on the board
/fpga/A2: U1.82 (IOT_78); also elsewhere on the board
/fpga/A3: U1.81 (IOT_77); also elsewhere on the board
/fpga/A4: U1.27 (IOB_27); also elsewhere on the board
/fpga/A5: U1.26 (IOB_26); also elsewhere on the board
/fpga/A6: U1.25 (IOL_12B); also elsewhere on the board
/fpga/A7: U1.24 (IOL_12A); also elsewhere on the board
/fpga/A8: U1.21 (IOL_10B); also elsewhere on the board
/fpga/A9: U1.20 (IOL_10A); also elsewhere on the board
/fpga/A16: U1.37 (IOB_37); also elsewhere on the board
/fpga/A17: U1.40 (IOB_41); also elsewhere on the board
/fpga/A18: U1.41 (IOB_42_CBSEL0); also elsewhere on the board
/fpga/A19: U1.42 (IOB_43_CBSEL1); also elsewhere on the board
/fpga/A_HIGH0: U1.56 (IOR_56); also elsewhere on the board
/fpga/A_HIGH1: U1.54 (IOR_55); also elsewhere on the board
/fpga/A_HIGH2: U1.53 (IOR_54); also elsewhere on the board
/fpga/A_HIGH3: U1.60 (IOR_59); also elsewhere on the board
/fpga/A_HIGH4: U1.59 (IOR_58); also elsewhere on the board
/fpga/A_HIGH5: U1.52 (IOR_53); also elsewhere on the board
/fpga/A_HIGH6: U1.57 (IOR_57); also elsewhere on the board
/fpga/CRESET_B: R17.2, U1.44 (CRESET_B); also elsewhere on the board
/fpga/D0: U1.85 (IOT_80); also elsewhere on the board
/fpga/D1: U1.86 (IOT_81); also elsewhere on the board
/fpga/D2: U1.87 (IOT_82); also elsewhere on the board
/fpga/D3: U1.91 (IOT_86); also elsewhere on the board
/fpga/D4: U1.4 (IOL_2B); also elsewhere on the board
/fpga/D5: U1.8 (IOL_3B); also elsewhere on the board
/fpga/D6: U1.7 (IOL_3A); also elsewhere on the board
/fpga/D7: U1.3 (IOL_2A); also elsewhere on the board
/fpga/D8: U1.96 (IOT_90); also elsewhere on the board
/fpga/D9: U1.95 (IOT_89); also elsewhere on the board
/fpga/D10: U1.94 (IOT_88); also elsewhere on the board
/fpga/D11: U1.93 (IOT_87); also elsewhere on the board
/fpga/D12: U1.68 (IOR_67); also elsewhere on the board
/fpga/D13: U1.65 (IOR_64); also elsewhere on the board
/fpga/D14: U1.66 (IOR_65); also elsewhere on the board
/fpga/D15: U1.64 (IOR_63); also elsewhere on the board
/fpga/FLASH_CLK: U1.48 (IOB_46_SCK); also elsewhere on the board
/fpga/FLASH_CS: U1.49 (IOB_47_SS); also elsewhere on the board
/fpga/FLASH_PICO: U1.45 (IOB_44_SDO); also elsewhere on the board
/fpga/FLASH_POCI: U1.46 (IOB_45_SDI); also elsewhere on the board
/fpga/MBC: U1.36 (IOB_34); also elsewhere on the board
/fpga/SCLK: U1.15 (IOL_7A_GBIN6); also elsewhere on the board
/fpga/TF_CLK: U1.72 (IOR_70); also elsewhere on the board
/fpga/TF_DETECT: U1.9 (IOL_5A); also elsewhere on the board
/fpga/TF_PICO: U1.73 (IOR_71); also elsewhere on the board
/fpga/TF_POCI: U1.71 (IOR_69); also elsewhere on the board
/fpga/TF_POW: U1.69 (IOR_68); also elsewhere on the board
/fpga/TF_SEL: U1.74 (IOR_72); also elsewhere on the board
/fpga//CARTINT: U1.28 (IOB_28); also elsewhere on the board
/fpga//IO: U1.30 (IOB_30); also elsewhere on the board
/fpga//MEM_OE: U1.100 (IOT_95); also elsewhere on the board
/fpga//MEM_WE: U1.51 (IOR_52); also elsewhere on the board
/fpga//OE: U1.33 (IOB_35_GBIN5); also elsewhere on the board
/fpga//PSRAM_LB: U1.99 (IOT_93); also elsewhere on the board
/fpga//PSRAM_UB: U1.97 (IOT_91); also elsewhere on the board
/fpga//SEL: U1.29 (IOB_29); also elsewhere on the board
/fpga//SEL_PSRAM1: U1.78 (IOT_73); also elsewhere on the board
/fpga//SEL_PSRAM2: U1.2 (IOL_1B); also elsewhere on the board
/fpga//SEL_SRAM: U1.79 (IOT_74); also elsewhere on the board
/fpga//WE: U1.34 (IOB_36_GBIN4); also elsewhere on the board
/fpga//μC_CS: U1.19 (IOL_8B); also elsewhere on the board
GND: C2.2, C3.2, C4.2, C6.2, C7.2, C8.2, C9.2, C10.2, C12.2, C14.2, C15.2, C16.2, C17.2, C18.2, C19.2, C20.2, U1.5 (GND), U1.17 (GND), U1.23 (GND), U1.32 (GND), U1.39 (GND), U1.47 (GND), U1.55 (GND), U1.70 (GND), U1.84 (GND), U1.98 (GND), U3.4 (GND); also elsewhere on the board
unnamed: TP2.1, U1.43 (CDONE)
unnamed: U1.10 (IOL_5B), U3.1 (ST)
unnamed: U1.13 (IOL_6B_GBIN7), U3.2 (OUT)

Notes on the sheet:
Core power
When NVCM programming is not used 3.3 V can also be used for VPP_2V5

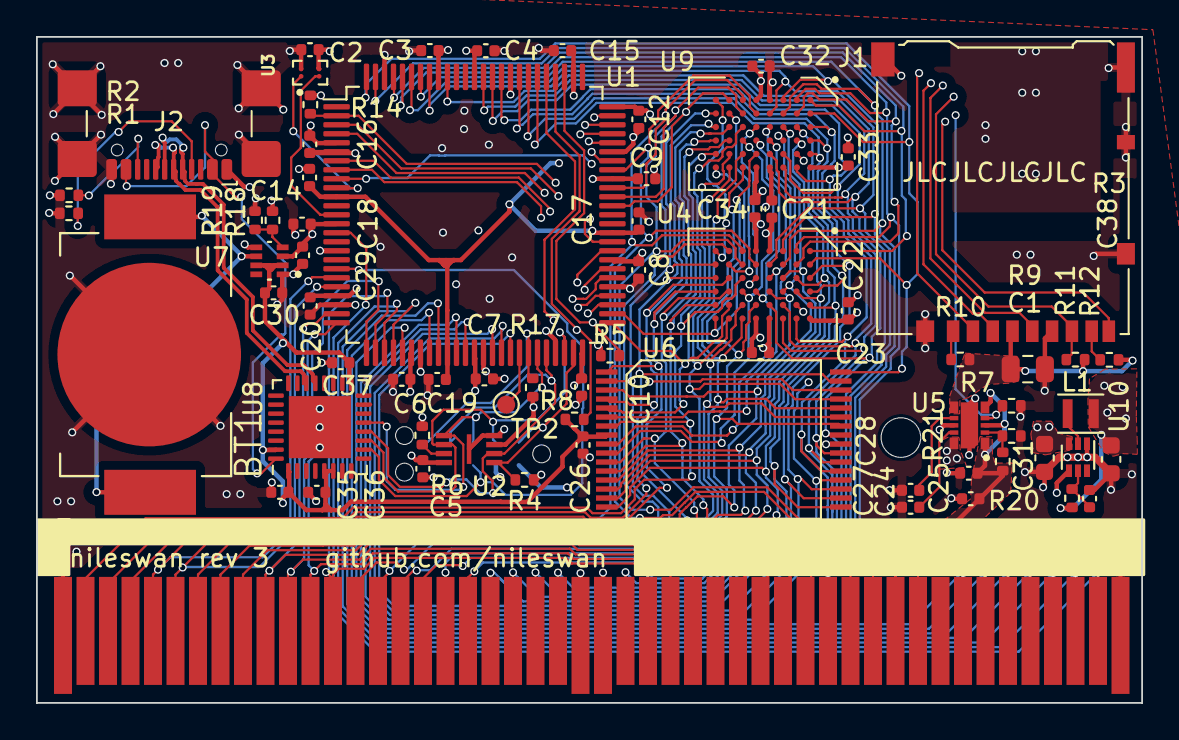
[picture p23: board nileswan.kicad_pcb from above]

Board: 4 copper layers, 61.4 x 37.0 mm, 71 parts (1 on the bottom side), 93 nets.

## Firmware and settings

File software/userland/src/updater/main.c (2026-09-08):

/**
 * Copyright (c) 2024, 2025 Adrian "asie" Siekierka
 *
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
 * You should have received a copy of the GNU General Public License along
 * with Nileswan Userland. If not, see <https://www.gnu.org/licenses/>.
 */

#include <nile/mcu.h>
#include <stdarg.h>
#include <stdio.h>
#include <string.h>
#include <wonderful.h>
#include <ws.h>
#include <ws/display.h>
#include <wsx/zx0.h>
#include "crc16.h"
#include "manifest.h"
#include "nile.h"
#include "nilefs.h"
#include "console.h"
#include "input.h"
#include "strings.h"

#define IRAM_IMPLEMENTATION
#include "iram.h"

#define UNPACK_BUFFER ((uint8_t __far*) MK_FP(0x1000, 0x0000))

uint8_t update_manifest_data[512];
um_version_t flash_version;
uint32_t flash_version_address;

uint32_t flash_id;
bool mcu_restarted = false;
int update_part;
bool update_verify;

static inline void use_error_colors(void) {
	if (ws_system_color_active()) {
		MEM_COLOR_PALETTE(0)[0] = 0x0F00;
		MEM_COLOR_PALETTE(0)[1] = 0x0FFF;
	} else {
		outportw(WS_SCR_PAL_PORT(0), WS_DISPLAY_MONO_PALETTE(7, 0, 2, 5));
	}
}

static void next_message(void) {
	if (!update_verify) {
		console_print_status(true);
		console_print_newline(0);
	} else {
		console_clear_current_line(0);
	}
}

__attribute__((noreturn))
static void update_halt(void) {
	cpu_irq_disable();
	while(1) cpu_halt();
}

__attribute__((noreturn))
static void updater_early_error(const char __far *text, uint16_t code) {
	console_print_status(false);
	console_print_newline(0);
	console_printf(0, text, code);
	update_halt();
}

__attribute__((noreturn))
static void updater_flash_error(const char __far* text, uint16_t code) {
	console_print_status(false);
	console_print_newline(0);
	console_printf(0, text, code);
	update_halt();
}

static void extract_um_cmd_flash(um_flash_cmd_t *cmd) {
	console_printf(0, update_verify ? s_verifying_part : s_unpacking_part, update_part);
	// Extract data to SRAM
	outportw(IO_BANK_2003_RAM, 0);
	if (cmd->cmd == UM_CMD_PACKED_FLASH) {
		wsx_zx0_decompress(UNPACK_BUFFER, MK_FP(cmd->load_segment, 0));
	} else {
		memcpy(UNPACK_BUFFER, MK_FP(cmd->load_segment, 0), cmd->unpacked_length);
	}
	// Calculate CRC16 sum
	uint16_t actual_crc = crc16(UNPACK_BUFFER, cmd->unpacked_length, 0);
	if (actual_crc != cmd->expected_crc) {
		console_print_status(false);
		console_print_newline(0);
		console_printf(0, s_crc_error_part, update_part);
		console_printf(0, s_crc_error_a_e, actual_crc, cmd->expected_crc);
		update_halt();
	}
}

static void run_um_cmd_flash(um_flash_cmd_t *cmd) {
	uint8_t flash_buffer[256];
	uint8_t verify_buffer[256];

	if (cmd->board_revision < 0x100 && inportb(IO_NILE_BOARD_REVISION) != cmd->board_revision)
		return;

	extract_um_cmd_flash(cmd);

	uint32_t start_address = cmd->flash_address;
	if (start_address & 0xFF) {
		updater_early_error(s_corrupt_data, start_address & 0xFF);
	}

	if (!update_verify) {
		console_print_status(true);
		console_print_newline(0);
		console_printf(0, s_erasing_part, update_part);

		uint32_t end_address = start_address + cmd->unpacked_length;
		uint32_t erase_address = (start_address & ~0xFFF);
		while (erase_address < end_address) {
			if (!nile_flash_erase_part(NILE_FLASH_CMD_ERASE_4K, erase_address)) {
				updater_flash_error(s_fatal_error_spi, 1);
			}
			erase_address += 4096;
		}

		console_print_status(true);
		console_print_newline(0);
		console_printf(0, s_flashing_part, update_part);

		uint32_t i = 0;
		while (start_address < end_address) {
			uint32_t len = end_address - start_address;
			if (len > sizeof(flash_buffer)) len = sizeof(flash_buffer);

			outportw(IO_BANK_2003_RAM, 0);
			memcpy(flash_buffer, UNPACK_BUFFER + i, len);
			if (!nile_flash_write_page(flash_buffer, start_address, len)) {
				updater_flash_error(s_fatal_error_spi, 2);
			}
			if (!nile_flash_read(verify_buffer, start_address, len)) {
				updater_flash_error(s_fatal_error_spi, 3);
			}

			outportw(IO_BANK_2003_RAM, 0);
			if (memcmp(verify_buffer, UNPACK_BUFFER + i, len)) {
				updater_flash_error(s_fatal_error_spi, 4);
			}

			start_address += len;
			i += len;
		}
	}

	next_message();
}

static void run_um_cmd_start_manifest(um_manifest_cmd_t *cmd) {
	uint8_t verify_buffer[sizeof(um_version_t)];

	um_version_t *version = &((um_header_t*) update_manifest_data)->version;
	version->partial_install = 0xFF;

	uint32_t start_address = cmd->flash_address;
	if (start_address & 0xFFF) {
		updater_early_error(s_corrupt_data, start_address & 0xFFF);
	}
	flash_version_address = start_address;

	if (!update_verify) {
		console_printf(0, s_erasing_part, update_part);

		if (!nile_flash_erase_part(NILE_FLASH_CMD_ERASE_4K, start_address)) {
			updater_flash_error(s_fatal_error_spi, 1);
		}

		console_print_status(true);
		console_print_newline(0);
		console_printf(0, s_flashing_part, update_part);

		if (!nile_flash_write_page(version, start_address, sizeof(um_version_t))) {
			updater_flash_error(s_fatal_error_spi, 2);
		}
		if (!nile_flash_read(verify_buffer, start_address, sizeof(um_version_t))) {
			updater_flash_error(s_fatal_error_spi, 3);
		}
		if (memcmp(verify_buffer, version, sizeof(um_version_t))) {
			updater_flash_error(s_fatal_error_spi, 4);
		}

		console_print_status(true);
		console_print_newline(0);
	}
}

static void run_um_cmd_finish_manifest(um_manifest_cmd_t *cmd) {
	uint8_t verify_buffer[sizeof(um_version_t)];

	um_version_t *version = &((um_header_t*) update_manifest_data)->version;
	version->partial_install = 0x00;

	uint32_t start_address = cmd->flash_address;
	if (start_address & 0xFFF) {
		updater_early_error(s_corrupt_data, start_address & 0xFFF);
	}

	if (!update_verify) {
		console_printf(0, s_flashing_part, update_part);

		if (!nile_flash_write_page(version, start_address, 12)) {
			updater_flash_error(s_fatal_error_spi, 2);
		}
		if (!nile_flash_read(verify_buffer, start_address, sizeof(um_version_t))) {
			updater_flash_error(s_fatal_error_spi, 3);
		}
		if (memcmp(verify_buffer, version, sizeof(um_version_t))) {
			updater_flash_error(s_fatal_error_spi, 4);
		}

		console_print_status(true);
		console_print_newline(0);
	}
}

#define MCU_FLASH_OPTR_ADDR 0x40022020U

static void run_um_cmd_mcu_flash(um_flash_cmd_t *cmd) {
	uint8_t flash_buffer[128];
	uint8_t verify_buffer[128];

	if (cmd->board_revision < 0x100 && inportb(IO_NILE_BOARD_REVISION) != cmd->board_revision)
		return;

	extract_um_cmd_flash(cmd);

	uint32_t start_address = cmd->flash_address;
	if (start_address & (NILE_MCU_FLASH_PAGE_SIZE - 1)) {
		updater_early_error(s_corrupt_data, start_address & (NILE_MCU_FLASH_PAGE_SIZE - 1));
	}

	if (!mcu_restarted) {
		next_message();
		console_print(0, s_rebooting_mcu);

		if (!nile_mcu_reset(true)) {
			updater_flash_error(s_error_mcu_reset, 0);
		}

		mcu_restarted = true;
	}

	if (!update_verify) {
		console_print_status(true);
		console_print_newline(0);
		console_printf(0, s_erasing_part, update_part);

		uint32_t end_address = start_address + cmd->unpacked_length;
		uint16_t page_start = start_address / NILE_MCU_FLASH_PAGE_SIZE;
		uint16_t page_count = (end_address + NILE_MCU_FLASH_PAGE_SIZE - 1 - start_address) / NILE_MCU_FLASH_PAGE_SIZE;

		if (!nile_mcu_boot_erase_memory(page_start, page_count))
			updater_flash_error(s_fatal_error_mcu, 1);

		console_print_status(true);
		console_print_newline(0);
		console_printf(0, s_flashing_part, update_part);

		start_address += NILE_MCU_FLASH_START;
		end_address += NILE_MCU_FLASH_START;

		uint32_t i = 0;
		while (start_address < end_address) {
			uint32_t len = end_address - start_address;
			if (len > sizeof(flash_buffer)) len = sizeof(flash_buffer);

			outportw(IO_BANK_2003_RAM, 0);
			memcpy(flash_buffer, UNPACK_BUFFER + i, len);
			if (!nile_mcu_boot_write_memory(start_address, flash_buffer, len)) {
				updater_flash_error(s_fatal_error_mcu, 2);
			}
			if (!nile_mcu_boot_read_memory(start_address, verify_buffer, len)) {
				updater_flash_error(s_fatal_error_mcu, 3);
			}

			outportw(IO_BANK_2003_RAM, 0);
			if (memcmp(verify_buffer, UNPACK_BUFFER + i, len)) {
				updater_flash_error(s_fatal_error_mcu, 4);
			}

			start_address += len;
			i += len;
		}

		console_print_status(true);
		console_print_newline(0);
		console_print(0, s_configuring_mcu);

		uint8_t flash_optr[4];
		uint8_t flash_optr_old[4];

		if (!nile_mcu_boot_read_memory(MCU_FLASH_OPTR_ADDR, flash_optr, sizeof(flash_optr)))
			updater_flash_error(s_fatal_error_mcu, 5);

		memcpy(flash_optr_old, flash_optr, 4);

        flash_optr[3] &= ~0x01; // Unset NBOOT_SEL
        flash_optr[2] |=  0x80; // Set BKPSRAM_HW_ERASE_DISABLE

        flash_optr[1] &= ~0x07; // Disable BOR

        if (memcmp(flash_optr_old, flash_optr, 4)) {
        	if (!nile_mcu_boot_write_memory(MCU_FLASH_OPTR_ADDR, flash_optr, sizeof(flash_optr)))
       			updater_flash_error(s_fatal_error_mcu, 6);
        }

        // Reboot MCU into non-bootloader mode to allow it to sleep properly on shutdown.
		nile_mcu_reset(false);
	}

	next_message();
}

static void run_um_cmd_check_board_revision_range(um_board_revision_range_cmd_t *cmd) {
	uint8_t rev = inportb(IO_NILE_BOARD_REVISION);
	if (rev < cmd->min_rev || rev > cmd->max_rev) {
		console_print_newline(0);
		console_printf(0, s_unsupported_board_revision, (int) rev);
		while(1) cpu_halt();
	}
}

void run_update_manifest(bool verify) {
	uint8_t *cmd_ptr = update_manifest_data;
	cmd_ptr += sizeof(um_header_t);

	update_verify = verify;
	update_part = 0;

	while (*cmd_ptr) {
		++update_part;

		switch (*cmd_ptr) {
			case UM_CMD_END:
				return;
			case UM_CMD_FLASH:
			case UM_CMD_PACKED_FLASH:
			{
				um_flash_cmd_t *cmd = (um_flash_cmd_t*) cmd_ptr;
				cmd_ptr += sizeof(um_flash_cmd_t);
				run_um_cmd_flash(cmd);
			} break;
			case UM_CMD_MCU_FLASH:
			case UM_CMD_MCU_PACKED_FLASH:
			{
				um_flash_cmd_t *cmd = (um_flash_cmd_t*) cmd_ptr;
				cmd_ptr += sizeof(um_flash_cmd_t);
				run_um_cmd_mcu_flash(cmd);
			} break;
			case UM_CMD_START_MANIFEST:
			{
				um_manifest_cmd_t *cmd = (um_manifest_cmd_t*) cmd_ptr;
				cmd_ptr += sizeof(um_manifest_cmd_t);
				run_um_cmd_start_manifest(cmd);
			} break;
			case UM_CMD_FINISH_MANIFEST:
			{
				um_manifest_cmd_t *cmd = (um_manifest_cmd_t*) cmd_ptr;
				cmd_ptr += sizeof(um_manifest_cmd_t);
				run_um_cmd_finish_manifest(cmd);
			} break;
			case UM_CMD_CHECK_BOARD_REVISION_RANGE:
			{
				um_board_revision_range_cmd_t *cmd = (um_board_revision_range_cmd_t*) cmd_ptr;
				cmd_ptr += sizeof(um_board_revision_range_cmd_t);
				run_um_cmd_check_board_revision_range(cmd);
			} break;
			default:
				updater_early_error(s_corrupt_data, *cmd_ptr);
				break;
		}
	}
}

static uint32_t supported_flash_chips[] = {
	NILE_FLASH_ID_BY25Q16BS,
	NILE_FLASH_ID_ZD25WQ16D,
	NILE_FLASH_ID_W25Q16JV_IQ,
	NILE_FLASH_ID_W25Q16JV_IM
};
#define SUPPORTED_FLASH_CHIPS_COUNT (sizeof(supported_flash_chips) / sizeof(uint32_t))
static bool flash_chip_supported(void) {
	for (int i = 0; i < SUPPORTED_FLASH_CHIPS_COUNT; i++)
		if (supported_flash_chips[i] == flash_id)
			return true;
	return false;
}

static const char __far version_template[] = "%d.%d.%d";
static const char __far version_template_commit[] = " (%08lx)";
static void print_version(um_version_t __far* version) {
	if (version->id != UM_ID) {
		console_print(0, s_unknown);
		return;
	}

	console_printf(0, version_template, version->major, version->minor, version->patch);
	if (flash_version.partial_install)
		console_print(0, s_install_corrupt);
	else
		console_printf(0, version_template_commit, __builtin_bswap32(*((uint32_t*) version->commit_id)));
}

__attribute__((interrupt, assume_ss_data))
void __far low_battery_nmi_handler(void) {
	console_clear();
	use_error_colors();
	console_draw(0, 7, CONSOLE_FLAG_CENTER, s_low_battery);
	while(1) cpu_halt();
}

void main(void) {
	cpu_irq_disable();
	ws_hwint_set_handler(HWINT_IDX_VBLANK, vblank_int_handler);
	ws_hwint_enable(HWINT_VBLANK);
	cpu_irq_enable();

	bool is_pcv2 = ws_system_get_model() == WS_MODEL_PCV2;

	console_init();

#ifdef NILESWAN_BRANDING
	console_draw_header(s_nileswan_update_title);
#else
	console_draw_header(s_update_title);
#endif
	console_print(0, s_license_header);
	console_print(0, s_initializing_updater);

	nile_io_unlock();
	nile_bank_unlock();

	nile_flash_wake();

	flash_id = nile_flash_read_id();
	if (!flash_chip_supported()) {
		console_print_status(false);
		console_print_newline(0);
		console_printf(0, s_unknown_flash_error, flash_id);
		while(1) cpu_halt();
	}

	// == LOW BATTERY NMI ENABLED ==
	ws_cpuint_set_handler(CPUINT_IDX_NMI, low_battery_nmi_handler);
	outportb(WS_INT_NMI_CTRL_PORT, WS_INT_NMI_CTRL_LOW_BATTERY);

	// Copy and validate update manifest
	uint16_t update_manifest_seg = (*((uint8_t __far*) MK_FP(0xF000, 0xFFF6))) << 8;
	uint16_t __far* update_manifest_start = MK_FP(update_manifest_seg, 0);
	if (update_manifest_start[0] > sizeof(update_manifest_data))
		updater_early_error(s_corrupt_data, update_manifest_seg);
	memset(update_manifest_data, 0, sizeof(update_manifest_data));
	memcpy(update_manifest_data, update_manifest_start + 2, update_manifest_start[0]);
	uint16_t actual_crc16 = crc16((const char*) update_manifest_data, update_manifest_start[0], 0);
	if (actual_crc16 != update_manifest_start[1])
		updater_early_error(s_corrupt_data, actual_crc16);

	console_print_status(true);
	console_print_newline(0);
	run_update_manifest(true);

	// Display update screen
	console_clear();
#ifdef NILESWAN_BRANDING
	console_print(CONSOLE_FLAG_MONOSPACE, s_nileswan_header);
	console_print(0, s_nileswan_update_title);
#else
	console_print(0, s_update_title);
#endif
	console_print_newline(0);

        um_version_t *update_version = &((um_header_t*) update_manifest_data)->version;

	console_print(0, s_installed_version);
	nile_flash_read(&flash_version, flash_version_address, sizeof(um_version_t));
	print_version(&flash_version);
	console_print_newline(0);

	console_print(0, s_update_version);
	if (update_version->id != UM_ID)
		updater_early_error(s_corrupt_data, update_version->id);
	print_version(update_version);
	console_print_newline(0);

	bool is_downgrade = flash_version.id == UM_ID && (update_version->major < flash_version.major || (update_version->major == flash_version.major && update_version->minor < flash_version.minor));
	if (is_downgrade) {
		if (flash_version_address < 0x40000) {
			console_print(0, s_warn_downgrade);
		} else {
			console_print(0, s_no_downgrade);
			update_halt();
		}
	} else if (flash_version_address < 0x40000) {
		console_print(0, s_warn_factory);
	}

	console_print_newline(0);
	console_print(0, s_update_disclaimer);
	console_print(0, is_pcv2 ? s_press_circle_continue : s_press_a_continue);
	console_print_newline(0);

	input_wait_key(KEY_A);

	outportb(WS_INT_NMI_CTRL_PORT, 0);
	// == LOW BATTERY NMI DISABLED ==

	if (flash_version_address < 0x40000) {
		nile_flash_write_unlock_global();
		nile_flash_write_sr1(0);
	}

	console_print_newline(0);
	run_update_manifest(false);

	nile_flash_sleep();
	outportb(IO_NILE_POW_CNT, 0);

	console_print_newline(0);
	console_print(0, s_update_success);
	if (ws_system_is_color()) {
		console_print(0, is_pcv2 ? s_press_circle_shutdown : s_press_a_shutdown);
		console_print_newline(0);
		input_wait_key(KEY_A);
		outportb(WS_SYSTEM_CTRL_COLOR2_PORT, WS_SYSTEM_CTRL_COLOR2_REQUEST_POWER_OFF);
	} else {
		console_print(0, s_manual_shutdown);
		console_print_newline(0);
	}

	update_halt();
}

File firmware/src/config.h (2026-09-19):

/**
 * Copyright (c) 2024 Adrian "asie" Siekierka
 *
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
 * You should have received a copy of the GNU General Public License along
 * with Nileswan MCU. If not, see <https://www.gnu.org/licenses/>.
 */

#ifndef _CONFIG_H_
#define _CONFIG_H_

// Feature flags

// Enable full EEPROM emulation.
// If disabled, READ and WDS/WEN commands are ignored (emulated on FPGA side only).
// #define CONFIG_FULL_EEPROM_EMULATION

#if !defined(BOARD_REVISION_rev9)
#define CONFIG_ENABLE_ADC
#endif
// #define CONFIG_ENABLE_CDC_DEBUG_PORT
#define CONFIG_ENABLE_CLOCK_LSE

// Use LSE-calibrated MSI for USB clock. Requires CONFIG_ENABLE_CLOCK_LSE.
// #define CONFIG_ENABLE_CLOCK_MSI_USB

// Firmware configuration

#define MCU_PROTOCOL_VERSION_MAJOR 1
#define MCU_PROTOCOL_VERSION_MINOR 2

#define MCU_SPI_MAX_PACKET_SIZE 512
#define MCU_SPI_RX_BUFFER_SIZE (MCU_SPI_MAX_PACKET_SIZE)
#define MCU_SPI_TX_BUFFER_SIZE ((MCU_SPI_MAX_PACKET_SIZE) + 2)

// ~2.01V
#define MCU_POWER_BATTERY_INSERTED_THRESHOLD   2500
// ~2.33V
#define MCU_POWER_BATTERY_SUFFICIENT_THRESHOLD 2900

// MCU-specific settings

#define MCU_UID_LENGTH 12

// Debug configuration

// #define CONFIG_MCU_FORCE_MAX_CLOCK
// #define CONFIG_DEBUG_SPI_NATIVE_CMD
// #define CONFIG_DEBUG_SPI_EEPROM_CMD
// #define CONFIG_DEBUG_SPI_RTC_CMD
// #define CONFIG_DEBUG_SPI_RTC_DISABLE_PROCESSING
// #define CONFIG_DEBUG_SPI_NATIVE_CDC_READ
// #define CONFIG_DEBUG_SPI_NATIVE_CDC_WRITE
// #define CONFIG_DEBUG_ACCEL

// GPIO A
#define MCU_PORT_SPI GPIOA
#define MCU_PIN_FPGA_BUSY LL_GPIO_PIN_1
#define MCU_PIN_TF_DETECT LL_GPIO_PIN_2
#define MCU_PIN_FPGA_IRQ LL_GPIO_PIN_3
#define MCU_PIN_SPI_NSS LL_GPIO_PIN_4
#define MCU_PIN_SPI_SCK LL_GPIO_PIN_5
#define MCU_PIN_SPI_POCI LL_GPIO_PIN_6
#define MCU_PIN_SPI_PICO LL_GPIO_PIN_7
#define MCU_PERIPH_SPI SPI1

#define MCU_PORT_I2C GPIOA
#define MCU_PIN_I2C_SCL LL_GPIO_PIN_9
#define MCU_PIN_I2C_SDA LL_GPIO_PIN_10
#define MCU_PIN_I2C_INT LL_GPIO_PIN_15
#define MCU_PERIPH_I2C I2C1

// GPIO B
#define MCU_PIN_BAT LL_GPIO_PIN_0
#define MCU_PIN_BAT_CHANNEL_ADC LL_ADC_CHANNEL_17
#define MCU_PIN_USB_POWER LL_GPIO_PIN_5
#define MCU_PIN_RUNS_ON_BAT LL_GPIO_PIN_7

#define MCU_DMA_CHANNEL_SPI_RX       LL_DMA_CHANNEL_2
#define MCU_DMA_CHANNEL_SPI_TX_DATA  LL_DMA_CHANNEL_3
#define MCU_DMA_CHANNEL_SPI_TX_EMPTY LL_DMA_CHANNEL_1

#define MCU_DMA_CHANNEL_I2C LL_DMA_CHANNEL_4

#define MCU_ACCEL_TIM TIM6

#define MCU_SPI_FREQ_384KHZ 0
#define MCU_SPI_FREQ_6MHZ   1
#define MCU_SPI_FREQ_24MHZ  2

#define MCU_IRQ_PRIORITY(n) (n)
#define MCU_IRQ_PRIORITY_PVD MCU_IRQ_PRIORITY(0)
#define MCU_IRQ_PRIORITY_SPI MCU_IRQ_PRIORITY(0)
#define MCU_IRQ_PRIORITY_SPI_DMA MCU_IRQ_PRIORITY(0)
#define MCU_IRQ_PRIORITY_RTC MCU_IRQ_PRIORITY(1)
#define MCU_IRQ_PRIORITY_I2C MCU_IRQ_PRIORITY(2)
#define MCU_IRQ_PRIORITY_I2C_DMA MCU_IRQ_PRIORITY(3)
#define MCU_IRQ_PRIORITY_USB MCU_IRQ_PRIORITY(3)
#define MCU_IRQ_PRIORITY_I2C_TIMER MCU_IRQ_PRIORITY(3)
#define MCU_IRQ_PRIORITY_DEFAULT MCU_IRQ_PRIORITY(3)

#define SAVE_ID_NONE 0xFFFFFFFF

#endif /* _CONFIG_H_ */

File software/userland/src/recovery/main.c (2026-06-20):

/**
 * Copyright (c) 2024, 2025 Adrian "asie" Siekierka
 *
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
 * You should have received a copy of the GNU General Public License along
 * with Nileswan Userland. If not, see <https://www.gnu.org/licenses/>.
 */

#include "console.h"
#include "config.h"
#include "ops/id_print.h"
#include "ops/ieeprom.h"
#include "ops/mcu.h"
#include "ops/mcu_setup.h"
#include "ops/tf_card.h"
#include "tests/button.h"
#include "tests/flash_fsm.h"
#include "tests/mcu.h"
#include "tests/memory.h"
#include "tests/rtc.h"
#include "tests/sram.h"
#include <nile/hardware.h>
#include <nilefs.h>
#include <stdbool.h>
#include <string.h>
#include <wonderful.h>
#include <ws.h>
#include <nile.h>
#include <ws/util.h>

#define IRAM_IMPLEMENTATION
#include "iram.h"

#include "input.h"
#include "menu.h"
#include "strings.h"

void console_press_any_key(void) {
	console_print(CONSOLE_FLAG_NO_SERIAL, s_press_any_key_to_continue);
	input_wait_any_key();
}

bool run_mfg_tests(void) {
	uint8_t board_rev = inportb(IO_NILE_BOARD_REVISION);

	console_print_header(s_caps_initialization);
	// MCU boot flag setup must run before MCU reset
	if (!op_mcu_setup_boot_flags()) return false;
	if (!op_mcu_setup_flash_firmware()) return false;

	// Automatic tests
	console_print_header(s_caps_test_suite);
	if (!test_flash_fsm()) return false;
	if (!test_rtc_clock()) return false;
	if (!test_mcu_eeprom()) return false;
	if (!test_mcu_save_id()) return false;
	if (!op_tf_card_test()) return false;
	if (board_rev >= 0x01) {
		if (!test_sram_32kb()) return false;
	}

	// Manual tests
	alert_mode_set(ALERT_ALERT);
	console_print_header(s_caps_test_suite_manual);
	console_print(CONSOLE_FLAG_MONOSPACE | CONSOLE_FLAG_NO_SERIAL, s_mfg_test_success0);
	console_print(CONSOLE_FLAG_MONOSPACE | CONSOLE_FLAG_NO_SERIAL, s_mfg_test_success1);
	console_print(CONSOLE_FLAG_MONOSPACE | CONSOLE_FLAG_NO_SERIAL, s_mfg_test_alert2);
	console_print(CONSOLE_FLAG_MONOSPACE | CONSOLE_FLAG_NO_SERIAL, s_mfg_test_alert3);
	console_print(CONSOLE_FLAG_MONOSPACE | CONSOLE_FLAG_NO_SERIAL, s_mfg_test_success1);
	console_print(CONSOLE_FLAG_MONOSPACE | CONSOLE_FLAG_NO_SERIAL, s_mfg_test_success0);
	input_wait_any_key();
	alert_mode_set(ALERT_NONE);
	if (!test_mcu_accelerometer()) return false;
	if (!test_button()) return false;

	console_print_header(s_caps_information);
	console_print(CONSOLE_FLAG_MONOSPACE, s_mfg_test_success0);
	console_print(CONSOLE_FLAG_MONOSPACE, s_mfg_test_success1);
	console_print(CONSOLE_FLAG_MONOSPACE, s_mfg_test_success2);
	console_print(CONSOLE_FLAG_MONOSPACE, s_mfg_test_success1);
	console_print(CONSOLE_FLAG_MONOSPACE, s_mfg_test_success0);
	console_print_newline(0);
	if (!op_id_print(0)) return false;

	return true;
}

bool console_warranty_disclaimer(void) {
	console_print(CONSOLE_FLAG_CENTER, s_warranty_disclaimer);
	console_print(0, s_warranty_disclaimer2);
	console_print(0, s_proceed);
	input_wait_any_key();
	console_print_newline(0);
	console_print_newline(0);
	return (input_pressed & KEY_A);
}

static const char __wf_rom* const __wf_rom menu_main[] = {
	s_console_recovery,
	s_tf_card_mgmt,
	s_cartridge_diagnostics,
	s_cartridge_recovery,
	s_run_manufacturing_test,
	s_license,
	s_exit,
#ifdef CONFIG_ENABLE_DEV_FEATURES
	s_dev_features,
#endif
	NULL
};

static void do_mfg_tests(void) {
	bool pass = run_mfg_tests();
	alert_mode_set(pass ? ALERT_PASS : ALERT_FAIL);
	if (!pass) {
		console_print(CONSOLE_FLAG_MONOSPACE, s_mfg_fail0);
		console_print(CONSOLE_FLAG_MONOSPACE, s_mfg_fail1);
		console_print(CONSOLE_FLAG_MONOSPACE, s_mfg_fail2);
	}
 	console_press_any_key();
	alert_mode_set(ALERT_NONE);
}

#ifndef PROGRAM_factory
__attribute__((section(".data")))
void fpga_core_reboot(void) {
	volatile uint8_t roml_bank = inportb(WS_CART_BANK_ROML_PORT);
	volatile uint16_t rom0_bank = inportw(WS_CART_EXTBANK_ROM0_PORT);
	volatile uint16_t rom1_bank = inportw(WS_CART_EXTBANK_ROM1_PORT);
	volatile uint16_t ram_bank = inportw(WS_CART_EXTBANK_RAM_PORT);
	volatile uint16_t bank_mask = inportw(NILE_SEG_MASK_PORT);

	// Start loading warmboot image
	outportb(IO_NILE_WARMBOOT_CNT, 0);
	// Configure HBlank timer to count down until 50ms have passed
	outportw(WS_TIMER_HBL_RELOAD_PORT, 601);
	outportw(WS_TIMER_CTRL_PORT, WS_TIMER_CTRL_HBL_ONESHOT);

	// Wait for FPGA init to finish
	while(inportw(WS_TIMER_HBL_COUNTER_PORT));

	// Restore some I/O ports
	outportb(NILE_POW_CNT_PORT, 0xDD);
	outportb(WS_CART_BANK_FLASH_PORT, 0);
	outportw(WS_CART_EXTBANK_ROM0_PORT, rom0_bank);
	outportw(WS_CART_EXTBANK_ROM1_PORT, rom1_bank);
	outportw(WS_CART_EXTBANK_RAM_PORT, ram_bank);
	outportb(WS_CART_BANK_ROML_PORT, roml_bank);
	outportw(NILE_SEG_MASK_PORT, bank_mask);
}
#endif

static const char __wf_rom* const __wf_rom menu_console_recovery[] = {
	s_disable_custom_splash,
	s_restore_tft_data,
	NULL
};

static void do_menu_console_recovery() {
	int option = 0;
	while (true) {
		console_clear();
		console_draw_header(s_console_recovery);
		option = menu_run(menu_console_recovery, option);
		switch (option) {
		case 0:
			console_clear();
			op_ieeprom_disable_custom_splash();
			console_press_any_key();
			break;
		case 1:
			console_clear();
			op_ieeprom_restore_tft_data();
			console_press_any_key();
			break;
		default:
			return;
		}
	}
}

static const char __wf_rom* const __wf_rom menu_card_mgmt[] = {
	s_tf_card_mount,
	s_benchmark_card_read_iram,
	s_benchmark_card_read_sram,
	s_benchmark_card_write,
	s_tf_card_format,
	NULL
};

static void do_menu_tf_card_mgmt(void) {
	int option = 0;
	while (true) {
		console_clear();
		console_draw_header(s_tf_card_mgmt);
		option = menu_run(menu_card_mgmt, option);
		switch (option) {
		case 0:
			console_clear();
			op_tf_card_init(true, true);
			console_press_any_key();
			break;
		case 1:
			console_clear();
			op_tf_card_benchmark_read(TF_BENCH_BUFFER_IRAM);
			console_press_any_key();
			break;
		case 2:
			console_clear();
			op_tf_card_benchmark_read(TF_BENCH_BUFFER_PSRAM);
			console_press_any_key();
			break;
		case 3:
			console_clear();
			op_tf_card_benchmark_write(TF_BENCH_BUFFER_IRAM);
			console_press_any_key();
			break;
		case 4:
			console_clear();
			op_tf_card_format();
			console_press_any_key();
			break;
		default:
			return;
		}
	}
}

static const char __wf_rom* const __wf_rom menu_retention_tests[] = {
	s_sram_retention_test1,
	s_eeprom_retention_test1,
	s_sram_retention_test2,
	s_eeprom_retention_test2,
	NULL
};
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

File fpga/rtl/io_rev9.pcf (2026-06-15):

set_io FastClk 34
set_io FastClkEnable 1

set_io -pullup yes Button 51

set_io AddrLo[0] 69
set_io AddrLo[1] 71
set_io AddrLo[2] 72
set_io AddrLo[3] 73
set_io AddrLo[4] 59
set_io AddrLo[5] 60
set_io AddrLo[6] 64
set_io AddrLo[7] 65
set_io AddrLo[8] 66
set_io Addr15 68

set_io AddrHi[0] 18
set_io AddrHi[1] 19
set_io AddrHi[2] 20
set_io AddrHi[3] 21

set_io Data[0] 78
set_io Data[1] 79
set_io Data[2] 80
set_io Data[3] 81
set_io Data[4] 82
set_io Data[5] 85
set_io Data[6] 83
set_io Data[7] 86
set_io Data[8] 24
set_io Data[9] 25
set_io Data[10] 26
set_io Data[11] 27
set_io Data[12] 93
set_io Data[13] 95
set_io Data[14] 94
set_io Data[15] 96

set_io MBC 89
set_io SClk 33

set_io nOE 13
set_io nWE 15
set_io nSel 9
set_io nIO 10

set_io nMem_OE 28
set_io nMem_WE 87

set_io nCartInt 8

set_io nPSRAM1Sel 30
set_io nPSRAM2Sel 36
set_io PSRAM_nUB 52
set_io PSRAM_nLB 29
set_io PSRAM_nZZ 16

set_io SRAMSel 74

set_io AddrExt[0] 42
set_io AddrExt[1] 40
set_io AddrExt[2] 37
set_io AddrExt[3] 100
set_io AddrExt[4] 99
set_io AddrExt[5] 97
set_io AddrExt[6] 41

set_io nMCUSel 56
set_io nFlashSel 49
set_io SPIClk 48
set_io SPIDo 45
set_io -pullup yes SPIDi 46

set_io nMCUReset 54
set_io MCUReady 57
set_io -pullup yes nMCUInt 53

set_io nTFSel 7
set_io TFDo 4
set_io TFDi 2
set_io TFClk 3
set_io TFPow 12

set_io SRAMA15 91

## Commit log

2025-06-01 recovery: print board revision ID
2025-06-19 ipl1: fix initialization in bootstrapped mode
    [main.c]
2025-06-19 ipl1/safe: fix bootstrapped/PCv2 support, add manufacturing test without memory test option
    [main.c]
2025-06-19 ipl1: fix boot on PCv2
    [main.c]
2025-06-21 updater: more user-friendly fatal error messages
    [config.h, main.c]
2025-06-23 mcu: power on SPI hardware only after battery check
2025-07-01 updater: fix marking unknown/corrupt version manifests as downgrades
    [main.c]
2025-07-01 firmware: parallelize USB write flush and SPI transfer
2025-07-02 firmware: -O2 -flto allows improving power draw in non-USB/EEPROM use cases
2025-07-04 firmware: improve native mode SPI reliability
2025-07-07 firmware, libnile: mcu fixes
    [mcu.c]
2025-07-14 firmware: fix LSI shutoff
    [mcu.c]
2025-07-17 docs: document current state of MCU/SPI transfer speeds
2025-07-20 firmware: stability improvements, add CDC clear command
    [config.h, spi.c, spi_cmd.c]
2025-07-20 firmware: tighten up native SPI command timings
    [config.h, spi.c, spi.h]
2025-08-13 ipl1/boot: fix error screen
    [main.c]
2025-08-24 firmware: fix mcu_update_clock_speed() spam
    [mcu.c]
2025-08-25 firmware: place SPI handler in SRAM
2025-08-26 initial implementation of accelerometer
2025-08-26 return availability of accelerometer in poll enable command
2025-08-27 Revert "firmware: place SPI handler in SRAM"
    This reverts commit 6152b6bbda4bd9667b90347446ec199fa0e67b0d.
    [spi.c]
2025-08-27 ipl1/safe: prevent doubleclicking inputs on exiting menus
    [main.c]
2025-08-27 recovery: fix RTC reset, add clock test
    [config.h, main.c]
2025-08-27 ipl1/safe: fix jittery input
    [main.c]
2025-08-27 ipl1/safe: actually fix jittery input
    [main.c]
2025-08-28 firmware: SPI code cleanup
2025-10-17 recovery: add on-device card formatting support
2025-10-21 ipl1/safe: allow changing SPI speed from 24 MHz to 384 KHz
2025-10-21 make: use latest board revision for spi.bin
2025-10-24 firmware, software: unify/clean up/add missing license headers
    [config.h]
2025-10-28 docs, firmware: add MCU version command, just in case
2025-10-28 updater: do not support out of range board revisions
2025-10-28 FPGA support for rev8/9 PCBs
2025-10-28 manifest: mark board revision 2 as supported
2025-10-28 fpga: add rev8 board revision
2025-10-28 ipl1/safe: print firmware version information
2025-10-28 userland/recovery: print out version manifests also here
2025-10-29 firmware: tweak accelerometer poll command
2025-10-29 recovery: add accelerometer test
2025-10-29 docs: mention accelerometer stub in emulator
2025-10-31 move PCB/shell data to a legacy folder - they are not yet up to date
    [74LVC245ABQ.step, AMPMAMPM_2.0 x 1.6 mm.step, BAT-HLD-012-SMT.step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]
2025-10-31 docs: add flowchart
2025-11-02 make: use separate spi.bin file for each board revision
2025-11-02 docs: document board revisions
2025-11-02 software/recovery: disable MCU resets when printing cartridge info via USB
2025-11-02 make: build rev2 board by default
2025-11-02 software/updater: fix files in update images not being padded to 4K correctly
    [config.h, main.c]
2025-11-03 recovery: add user guidance to USB print option
2025-11-03 rtc: use millisecond-based timeout
2025-11-03 recovery: add missing SPI control
2025-11-03 firmware: only speed up clock from 16 MHz to 48 MHz when USB peripheral mounted
2025-11-10 firmware: send error bit on invalid commands
    [spi.c, spi_cmd.c]
2025-11-11 recovery: fix TF card tests requiring a force init
    [main.c]
2025-11-12 recovery: stabilize exit to ipl0
    [main.c]
2025-11-16 recovery: clear "restarting mcu" line on information printout
2025-11-20 recovery: add TF card stability test
    [main.c]
2025-11-21 recovery: add SRAM<->PSRAM stability test
    [main.c]
2025-11-22 firmware: update tinyusb, fix device qualifier descriptor
2026-02-10 firmware: support for ADC battery voltage measurement
2026-02-14 fpga, recovery: button held IRQ
2026-02-14 fpga: fix button held IRQ
    [nileswan.sv]
2026-02-15 firmware: initialize TF_DETECT pin
2026-02-16 recovery: add (untested) TF card insert/remove test
2026-02-27 firmware: fix USB interrupt handler race condition on disconnect
    [mcu.c]
2026-02-27 firmware: tweak ADC readout code
2026-02-28 firmware: make ADC feature configurable
2026-03-03 fpga: correctly emulate port 0xC0 as 6-bit
    [nileswan.sv]
2026-03-04 avoid using infered tri state logic for data pins
    [nileswan.sv]
2026-03-04 firmware: work around rev8+ RTC stability issue
    [spi.c]
2026-03-04 recovery: fix not booting into updated FPGA core
    [main.c]
2026-03-05 firmware: temporarily speed up RTC to work around stability issues
    [mcu.c]
2026-03-12 firmware: temporarily work around stability issues in EEPROM mode with USB connected
    [mcu.c]
2026-03-17 firmware: mark USB device as self-powered
2026-03-19 firmware: minor SPI handling optimizations
2026-03-19 firmware: further minor SPI code size optimizations
2026-03-29 fpga: board revision 9a
2026-04-26 add shell model files
    [nileswanBottomPart.stl, nileswanButton.stl, nileswanLid.stl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]
2026-05-03 mcu: new battery measurement code
2026-05-03 mcu: fix accelerometer polling at 24 MHz system clock
    [accel.c]
2026-05-05 mcu: optimize pulldown use in battery measurement code
2026-05-10 ipl0: fix slow SPI mode being activated when boot ROM is unlocked
2026-05-16 updater: update SPI flash chip list
2026-05-29 ipl1/safe: fix reading flash UUID if 24 MHz oscillator hardware failure
    [main.c]
2026-05-29 ipl1/safe: fix flash readout regression
    [main.c]
2026-05-30 ipl1/safe: only read out flash UUID at 24 MHz if SPI speed limit disabled
2026-06-04 ipl1: board check should not test cart A16-A19 if PSRAM is broken
2026-06-05 firmware: minor reliability fixes
    [mcu.c, spi.c]
2026-06-15 firmware: reorder GPIO/ADC init
2026-06-15 enable FPGA side pull up for mcu interrupt
2026-06-16 firmware: "estimate" battery voltage when ADC disabled (outside of native mode)
2026-06-20 recovery: fix EEPROM retention test. again
    [spi_cmd.c]
2026-06-24 update shell 3D models
    [nileswanButton.stl, nileswanLid.stl]
2026-08-27 updater: reboot MCU into bootloader mode on update completion
    [main.c]
2026-08-29 ipl1/boot: add rudimentary pin contact check
2026-08-29 docs: document pin contact error
2026-08-30 ipl1/boot: optimize pin contact check code, -26 bytes
2026-09-10 ipl1: new pin contact check method
2026-09-15 ipl0: improve compatibility with prototype consoles
2026-09-19 firmware: mcu: disable ADC clock when sleeping
2026-09-20 recovery: ship per-board MCU images
2026-11-07 firmware: fix RTC non-zero -> non-zero interrupt configuration transitions

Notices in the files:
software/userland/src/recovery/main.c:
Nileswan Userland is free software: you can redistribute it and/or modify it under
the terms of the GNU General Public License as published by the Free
